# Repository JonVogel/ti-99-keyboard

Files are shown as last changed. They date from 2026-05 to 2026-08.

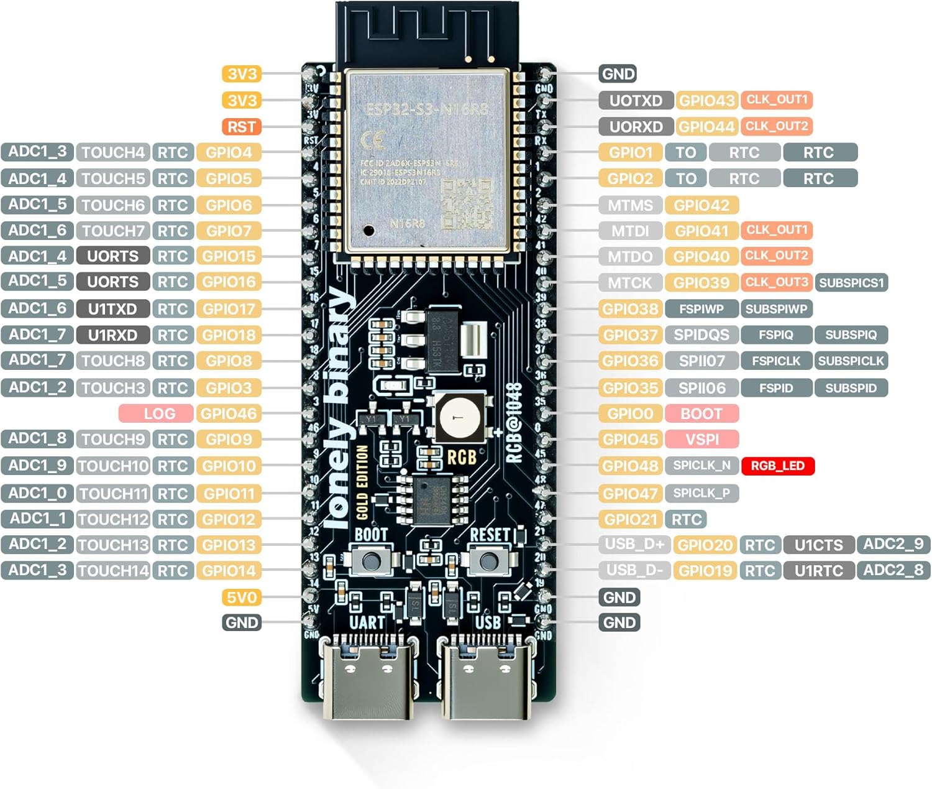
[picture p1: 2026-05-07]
81z4NkTU8bL._AC_SL1500_.jpg

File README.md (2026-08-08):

# TI-99/4A Modern Keyboard Adapter

An ESP32-S3 based adapter that lets you use a modern Bluetooth (or USB) keyboard
with a Texas Instruments TI-99/4A home computer.

The adapter installs inside the TI in place of the original keyboard connector
and emulates the original 6×8 key matrix, translating HID reports from a BLE/USB
keyboard into key presses the console's keyboard scan sees as if they came from
the original keyboard. The original keyboard can optionally run in parallel.

## Features

- **Bluetooth LE keyboard input** using the **NimBLE-Arduino** stack
  - Auto-pairing / "Just Works" bonding on first use
  - Auto-reconnect by saved address after sleep or power cycle
  - **F12** on the keyboard enters pairing mode for a new keyboard
- **Status LED** (onboard WS2812) shows connection state
- Full punctuation and symbol mapping, including the FCTN-generated characters
  (`? _ [ ] { } ' " \ | ~` `` ` `` `: < >`)
- System keys that work on real hardware: **QUIT** (Alt+=) and **CLEAR / BREAK**
  (Alt+4) to stop a running program
- Software **Alpha Lock** that fixes the original joystick-UP bug (see below)
- Optional **parallel original keyboard** — both can drive the matrix at once
- **USB keyboard input** via the native USB-OTG host port (using `EspUsbHost`),
  usable alongside or instead of BLE

## Hardware — Bill of Materials

The adapter comes in **two editions** that are electrically identical and run
the same firmware; they differ only in how the 16 level-shifter channels are
built:

- **DIY edition** (board rev ≤6): all through-hole, level shifting on four
  plug-in BOB-12009 modules — buildable with just a soldering iron.
- **Assembled edition** (board rev 7+): the shifters are 48 SMT parts
  populated by JLCPCB during fabrication. Hand work remaining: the ESP32
  (header pins on the module + two 1×22 sockets on the board, ~88 joints)
  and the connectors — real soldering, just none of the shifter fabric.

### Common parts (both editions)

| Part | Purpose |
|---|---|
| Hosyond ESP32-S3 N16R8 dev board (USB-C, WROOM-1, 16MB flash, 8MB PSRAM) — sold in 3-packs on Amazon | MCU with USB host and BLE |
| 2× 1×22 female socket strips, 2.54mm | Sockets the ESP32 dev board (never solder the module directly) |
| 2× 1×15 male pin headers, 2.54mm (snap from 1×40 breakaway strips — e.g. Adam Tech `PH1-40-UA`, DigiKey ~$0.48/strip) | J10 (to the TI) and J20 (optional original keyboard) |
| 1×2 + 1×1 male header pins (from the same breakaway strips) | J9 bench power header, J15 spare-channel pad |
| TI PSU daisy-chain header — Molex KK-396 4-pin, `09-65-2048` (DigiKey **WM18825-ND**; alt `26-60-4040` / **WM4622-ND**) | Passes the TI's power through the board; the TI mainboard's existing female plug mates here (J14) |
| PSU-side mating plug — Molex `09-50-3041` housing (DigiKey **WM2102-ND**) + 4× `08-50-0106` crimp terminals (DigiKey **WM2300-ND**) + ~30cm of 22 AWG stranded wire | Cable from the J13 solder pads to the TI power supply's header |
| 15-pin female-to-female keyboard ribbon (DIY from bulk Dupont parts, ~$1.5–3.5/cable, no crimping — see note below; or ready-made aftermarket TI ribbon, ~$8) | Connects the adapter's male header to the TI's male keyboard header |

No voltage regulator is needed — the board runs on regulated +5V taken
straight from the TI PSU via the power daisy-chain. Crimp tool for the KK
terminals: IWISS SN-48B (~$20), or fold-and-solder the terminal barrels.

### DIY edition — additional parts (board rev ≤6)

| Part | Purpose |
|---|---|
| PCB fabbed from `pcb/gerbers/ti99-kb-adapter_r6.zip` (2-layer, 1.6mm, HASL — ~$1/board at JLCPCB) | The carrier board, all through-hole |
| 4× BOB-12009 BSS138 level-shifter breakouts (SparkFun ~$3.50 ea, or AliExpress clones) | The 16 shifter channels (4 per module) |
| 8× 1×6 female socket strips, 2.54mm + male header pins on each BOB | Sockets the four BOB modules |

**Solder generously on the BOB headers** — under-heated joints there were the
single most common build fault. Test every finished board with
`test-matrix-loopback/` (onboard LED: green = good, red = bad).

### Assembled edition — what to order (board rev 7+)

| Item | Details |
|---|---|
| JLCPCB order with **PCB Assembly (Economic, Top side)** using the three files in `pcb/gerbers/`: `ti99-kb-adapter_r7.zip` + `ti99-kb-adapter_BOM.csv` + `ti99-kb-adapter_CPL.csv` | Boards arrive with all 48 shifter parts (16× BSS138 `C78284`, 32× 10kΩ `C17414`) machine-soldered — ~$3/board + shipping in qty 10 |

Then add the common parts above. Still hand-soldered: the ESP32 module's
header pins, the two 1×22 board sockets, and all connectors (~120 joints) —
what assembly removes is the shifter fabric and the DIY tier's BOB/socket
work. Run `test-matrix-loopback/` after the ESP32 goes in — LED green means the
whole path (module, sockets, traces, every shifter channel) is proven in
one shot.

The adapter is intended for permanent installation inside a TI-99/4A with the
original keyboard removed (or run in parallel) and a 3D-printed cover over the
keyboard opening.

> **Sourcing the keyboard ribbon (cheap DIY):** the cable is a straight 15-way
> female-to-female run — both the adapter and the TI motherboard expose 1×15 male
> headers. Instead of a ready-made aftermarket TI ribbon (arcadeshopper, ~$8),
> build it from bulk commodity Dupont parts for ~$1.5–3.5/cable with **no
> crimping and no shells to strip**:
> - **15× female-to-female _no-shell_ pre-crimped 2.54mm leads** per cable —
>   [AliExpress](https://www.aliexpress.us/item/3256804990855815.html)
>   (search: *"Dupont 2.54mm female-to-female no-shell pre-crimped jumper wire 40P"*).
> - **2× 1×15 single-row Dupont female housings** per cable —
>   [AliExpress](https://www.aliexpress.us/item/3256806021686798.html)
>   (search: *"Dupont 2.54mm 1x15P housing female single row"*).
>
> Slide 15 bare pins into each housing — that's the whole assembly. A genuine
> Molex 1×15 housing (`50-57-9315`, DigiKey ~$1) also fits, but only accepts Molex
> crimp terminals — commodity Dupont pins won't lock in it, so stay all-Dupont.
> AliExpress links rot; the search terms are the durable fallback. Orientation
> gotcha is noted under the pinout below (red stripe = pin 15).

> **Note:** an earlier revision used TXS0108E auto-direction level shifters. They
> do **not** work for a keyboard matrix — the auto-direction detector can't
> handle open-drain / resistive loads and channels latch or oscillate. The design
> uses **BSS138 discrete MOSFET shifters**, which are bidirectional by physics and
> handle open-drain cleanly. Do not substitute TXS0108E.

## TI-99/4A Keyboard Connector Pinout

The TI's internal keyboard connector is a 1×15 single-row 0.1" header. The console
drives **six column lines** low one at a time (via a 74LS156, pulled up with 1kΩ)
and reads **eight row lines** back (into the TMS9901, pulled up with 10kΩ). The
adapter reads the columns (inputs) and drives the rows (open-drain outputs).

GPIOs below are the **v5 (straight-ribbon) mapping**: the flat ribbon lands
adapter connector (J10) pin *p* on TI pin 16−*p*, and the firmware pin map
mirrors to match. (Rev-3 boards used a 180°-twisted ribbon and a different
GPIO map — see the `v3` git tag.)

| TI pin | Signal | Matrix | ESP32 GPIO | Direction |
|:---:|---|---|:---:|---|
| 1  | INT5  | row 2 | 13 | ESP32 → TI (drive) |
| 2  | INT6  | row 3 | 12 | ESP32 → TI (drive) |
| 3  | INT8  | row 5 | 11 | ESP32 → TI (drive) |
| 4  | INT4  | row 1 | 10 | ESP32 → TI (drive) |
| 5  | INT3  | row 0 | 9  | ESP32 → TI (drive) |
| 6  | P5 | Alpha Lock | 3 | wired, never driven (software alpha lock) |
| 7  | INT7  | row 7 | 8  | ESP32 → TI (drive) |
| 8  | 1Y1 | col 0 | 18 | TI → ESP32 (read) |
| 9  | 1Y0 | col 4 | 17 | TI → ESP32 (read) |
| 10 | INT9  | row 6 | 16 | ESP32 → TI (drive) |
| 11 | INT10 | row 4 | 15 | ESP32 → TI (drive) |
| 12 | 2Y0 | col 5 | 7  | TI → ESP32 (read) |
| 13 | 2Y1 | col 1 | 6  | TI → ESP32 (read) |
| 14 | 2Y2 | col 2 | 5  | TI → ESP32 (read) |
| 15 | 2Y3 | col 3 | 4  | TI → ESP32 (read) |

A 16th level-shifter channel (GPIO14 → **J15 "SPARE" solder pad**) is wired as a
repair path: if any matrix GPIO or shifter channel dies, jumper J15 to the dead
line's pad and remap that line's `#define` to GPIO14 — no board respin needed.

> **Ribbon orientation gotcha:** aftermarket TI keyboard ribbons mark **pin 15**
> with the red stripe, not pin 1. Verify against the silkscreen before plugging in.

### How the matrix output works

A hardware timer samples all six column inputs at ~200 kHz. Each column is
debounced asymmetrically — it becomes *active* on the first LOW sample (so the row
is driven before the ROM reads it) and only releases after two consecutive HIGH
samples (so ribbon coupling can't glitch a held key). The rows driven are the OR
of the pressed keys in every currently-active column, so an ordinary one-column
scan drives exactly that column, while the console's deliberately-overlapping QUIT
and CLEAR scans (which strobe two columns at once) are presented correctly. Rows
are open-drain, so the original keyboard can coexist on the same lines.

The dedicated Alpha Lock line (TI pin 6) is intentionally **never driven** — see
below.

## Software Build

The BLE library `BleHidHost/` lives in-tree and is picked up automatically; the
only external dependency to install is **NimBLE-Arduino**.

### Toolchain

Builds with `arduino-cli` via the included `build.bat` (Windows). FQBN:

```
esp32:esp32:esp32s3:PartitionScheme=no_ota,FlashSize=16M,PSRAM=opi
```

- `build.bat compile` — compile only
- `build.bat` — compile + upload (default COM port)
- `build.bat upload COM7` — upload to a specific port
- `build.bat monitor COM7` — serial monitor at 115200 baud

### Arduino IDE alternative

1. Install **ESP32 board support** (Boards Manager → "esp32 by Espressif")
2. Install **NimBLE-Arduino** (Library Manager → search "NimBLE-Arduino")
3. Point the sketchbook libraries at the in-tree `BleHidHost/` folder (or copy it
   into `~/Documents/Arduino/libraries/`)

### Board settings

- Board: **ESP32S3 Dev Module**
- Flash Size: **16MB**, PSRAM: **OPI PSRAM**, Partition Scheme: **no_ota**
- USB CDC On Boot: **Disabled** (frees the USB-OTG port for host mode; use the
  UART port for the serial monitor)

### Selecting input mode

At the top of `ti-99-keyboard.ino`:

```cpp
// #define INPUT_USB   // USB keyboard via USB-OTG port (currently disabled)
#define INPUT_BLE      // Bluetooth LE HID keyboard
```

## Usage

### First-time BLE pairing

1. Power on the ESP32 — the LED pulses purple (scanning)
2. Put your keyboard in pairing mode
3. The ESP32 finds the keyboard, pairs, bonds, and saves its address to NVS
4. LED turns dim green when ready; it reconnects automatically on later boots

### Re-pairing a different keyboard

Press **F12** on the currently connected keyboard. It disconnects, the ESP32
opens a 30-second pairing window (LED pulses blue), and any HID keyboard put in
pairing mode during that window is adopted as the new peer.

### LED status

| Color | Meaning |
|---|---|
| Pulsing blue | Startup or pairing mode |
| Pulsing purple | Scanning for keyboard |
| Steady dim green | Keyboard connected, idle |
| Bright green flash | Key pressed |
| Red blink | Error |

## Key Mapping

Modifiers pass straight through; the host **Alt** key acts as TI **FCTN**.

| Modern key | TI-99/4A |
|---|---|
| Alt | FCTN |
| Ctrl | CTRL |
| Shift | SHIFT |
| Caps Lock | Alpha Lock (software-emulated; see below) |

Punctuation and symbols (unshifted / shifted):

| Key | Unshifted | Shifted |
|-----|---|---|
| `-` | `-` | `_` (FCTN+U) |
| `=` | `=` | `+` |
| `/` | `/` | `?` (FCTN+I) |
| `;` | `;` | `:` |
| `,` | `,` | `<` |
| `.` | `.` | `>` |
| `'` | `'` (FCTN+O) | `"` (FCTN+P) |
| `[` | `[` (FCTN+R) | `{` (FCTN+F) |
| `]` | `]` (FCTN+T) | `}` (FCTN+G) |
| `\` | `\` (FCTN+Z) | `\|` (FCTN+A) |
| `` ` `` | `` ` `` (FCTN+C) | `~` (FCTN+W) |

Editing / function keys:

| Modern key | TI-99/4A |
|---|---|
| Esc | FCTN+9 (BACK) |
| Backspace | FCTN+S |
| Tab | FCTN+7 |
| Delete | FCTN+1 |
| Arrows | FCTN+E / S / D / X (up / left / right / down) |
| F1–F10 | FCTN+1…0 (DEL, INS, ERASE, CLEAR, BEGIN, PROC'D, AID, REDO, BACK, …) |
| F11 | Toggle type-ahead buffer on/off |
| F12 | Enter BLE pairing mode (not forwarded to the TI) |

The F-key shortcuts let you press the standard TI FCTN+digit combos with a single
key. Two system combos worth calling out, both verified on real hardware:

- **Alt+=** → FCTN+= = **QUIT** (soft-resets to the master title screen)
- **Alt+4** (or **F4**) → FCTN+4 = **CLEAR** (breaks a running BASIC program)

### Alpha Lock and joystick compatibility

The original TI-99/4A has a notorious hardware bug: the Alpha Lock key shares an
electrical signal with joystick UP, so any game played with Alpha Lock engaged
sees a permanent UP input. The classic fix was to physically pop the Alpha Lock
key out of its socket before playing.

This adapter sidesteps the bug entirely by implementing Alpha Lock in software.
When Caps Lock is on, the adapter injects SHIFT into letter keypresses (producing
capital letters via the normal keyboard-scan path) and **never drives the
dedicated Alpha Lock line** (TI pin 6). Joysticks therefore work correctly
regardless of Caps Lock state, and numbers/punctuation are unaffected by Caps
Lock — matching the original Alpha Lock semantics.

## Status

- **BLE keyboard input:** working; tested with the RoyalAxe / ProtoArc L75.
- **TI-99/4A matrix output:** working on real hardware — typing, SHIFT/CTRL/FCTN,
  full punctuation, QUIT, and CLEAR/BREAK, with the original keyboard usable in
  parallel.
- **USB keyboard input:** working — plug a USB keyboard into the ESP32's native
  USB-OTG port (`EspUsbHost`); runs alongside BLE.

## License

MIT — see [LICENSE](LICENSE).

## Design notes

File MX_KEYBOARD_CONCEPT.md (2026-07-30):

# Future project: "B-P board" — MX mechanical keyboard with built-in BLE/USB adapter

Working name: **B-P** (BLE + Physical).
Status: **concept — parked until V5 is bench-validated.** Captured 2026-07-22.
Reference hardware: an **838-MX99 is on order** (~$30 base pre-order) to serve
as the mechanical reference — switch layout in the TI opening, bracket design,
ALPS keycap adapters — and to bench-validate J20 coexistence with the adapter.

## The idea

One keyboard-sized PCB that is both an in-case MX mechanical keyboard for the
TI-99/4A *and* the existing USB/BLE adapter: local MX switches, an ESP32-S3,
and the proven 16-channel BSS138 fabric driving the TI's 6×8 matrix. The TI
only ever sees the synthesized matrix; local keys, BLE keyboards, and USB
keyboards are all just input sources.

## Market context

- **shift838 838-MX99** (2026): drop-in MX replacement keyboard, ~$217
  assembled. Its micro does matrix synthesis (evidenced by alpha-lock memory
  and a destructive backspace — impossible with passive switch wiring), i.e.
  the same architecture class as this project's adapter, fed from local
  switches instead of HID. No BLE/USB.
- **Our differentiator:** the in-case mechanical keyboard is *also* the
  wireless adapter — couch typing over BLE, USB host, plus all existing
  firmware features (software alpha lock/joystick fix, FCTN combos,
  QUIT/CLEAR, type-ahead), field-updatable, on a battle-tested codebase.
- The two products can coexist today: an MX99 (or original keyboard) plugs
  into the adapter's J20. The fusion board makes that one PCB.

## Decisions already made

- **No backlight.** Deliberately scrapped — removes the LED chain, the
  brightness UI, and the TI-PSU current-budget problem entirely.
- **Power: regulated +5V straight from the TI PSU** via the J13/J14
  daisy-chain, same as the adapter (the originally planned 12V→5V buck
  proved unnecessary and is not part of any build).
- **TI-facing half is V5 verbatim** — same 16-channel topology (15 lines +
  SPARE), same firmware pin philosophy, but with the BSS138s + resistors as
  on-board parts (~$3) instead of BOB daughterboards.
- **Local keys are a third input source.** A timer-driven scan (structurally
  the same as the existing debounced column sampler) emits key events into
  the same pipeline `processHidReport` feeds. No new synthesis logic.

## Electrical design points

- **Switch matrix:** ~50 keys (TI's 48 + extras à la MX99's added keys),
  7×8 matrix, **one diode per switch** (NKRO).
- **GPIO budget:** S3 has ~28 comfortable GPIOs; the TI fabric uses 16,
  leaving ~12 — three short of a direct 7×8 scan. Answer: hang the switch
  matrix off **chained 74HC165/595 shift registers** (3–4 GPIOs, any matrix
  size) or an **MCP23017 I²C expander** (2 GPIOs, 16 lines). ~$1–2. The
  fabric keeps its pins, including SPARE.
- **USB-OTG (GPIO19/20) stays reserved** so USB host input remains available.

## The long poles (mechanical, not electrical)

- Switch layout matching the TI keyboard opening; plate; stabilizers
  (6U spacebar per MX99 precedent frees room for extra keys).
- Mounting bracket into the TI case (MX99 ships 3D-printed brackets —
  proves feasibility).
- **Keycaps are the hard/expensive part.** No off-shelf TI legends. Paths:
  generic MX caps (budget), or MX-to-ALPS adapters carrying original TI
  keycaps (838's approach — best authentic look).

## Cost sketch

Switches $15–25 · hot-swap sockets ~$5 · keyboard-size 2-layer PCB ~$5 (JLC)
· ESP32-S3 module ~$6 · on-board shifters ~$3 · connectors/stabs ~$10 ·
caps $20–40 → **BOM ≈ $60–90**, against a $217 assembled competitor with
fewer features.

## Path

1. Fab + bench-validate **V5** (proves fabric, firmware, straight ribbon).
2. Keyboard PCB = V5's TI half + switch matrix + scan chain on one board;
   firmware delta = local scan source.
3. Mechanical design (layout/plate/bracket/caps) in parallel — the real
   schedule driver.
4. End state: two SKUs (adapter, keyboard) sharing one firmware and one
   proven channel design.

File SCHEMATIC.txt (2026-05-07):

TI-99/4A Keyboard Adapter — Wiring Schematic
=============================================

  ESP32-S3 N16R8 dev board (Lonely Binary Gold Edition).
  Physical pin numbers count from pin 1 (3V3) at top of left header
  down to pin 22 (GND) at the bottom. Silkscreen labels in brackets.

                     TI-99/4A +12V Rail
                            |
                   +--------+--------+
                   |  Buck Converter  |
                   |    12V -> 5V     |
                   +--------+--------+
                            |
                          5V Bus ------+----------+----------+
                            |          |          |          |
                            |       TXS#1 VB  TXS#2 VB  ESP32 pin 21 [5V0]
                            |
                          GND Bus -----+----------+----------+----------+
                                       |          |          |          |
                                    TXS#1 GND  TXS#2 GND  ESP32       TI GND
                                                           pin 22 [GND]

                     ESP32 pin 1 [3V3] +----------+----------+----------+
                                       |          |          |          |
                                    TXS#1 VA  TXS#1 OE  TXS#2 VA  TXS#2 OE

  ESP32-S3 N16R8                   TXS0108E #1                      TI Keyboard
  Left Side Header                 (6 rows + 2 cols)                 Connector
  ==================               =================                 =========

  Physical                         A side          B side
  Pin #  [silkscreen]              ------          ------

    1    [3V3] ── (power, see above)
    2    [3V3] ── (power, see above)
    3    [RST] ── (do NOT connect to OE)

    4    [4]  GPIO 4  ─────── A8      B8 ─────────────────── Pin 1  (INT5,  row)
    5    [5]  GPIO 5  ─────── A7      B7 ─────────────────── Pin 2  (INT6,  row)
    6    [6]  GPIO 6  ─────── A6      B6 ─────────────────── Pin 3  (INT8,  row)
    7    [7]  GPIO 7  ─────── A5      B5 ─────────────────── Pin 4  (INT4,  row)
    8    [15] GPIO 15 ─────── A4      B4 ─────────────────── Pin 5  (INT3,  row)
                                                   (nc) ──── Pin 6  (P5, Alpha Lock)
    9    [16] GPIO 16 ─────── A3      B3 ─────────────────── Pin 7  (INT7,  row)
   10    [17] GPIO 17 ─────── A2      B2 ─────────────────── Pin 8  (1Y1,   col 0)
   11    [18] GPIO 18 ─────── A1      B1 ─────────────────── Pin 9  (1Y0,   col 4)

   12    [8]  GPIO 8  ── (unused)
   13    [3]  GPIO 3  ── (unused)
   14    [46] GPIO 46 ── (LOG pin, unused — gap between TXS boards)

                                   TXS0108E #2
                                   (2 rows + 4 cols)

                                   A side          B side
                                   ------          ------

   15    [9]  GPIO 9  ─────── A8      B8 ─────────────────── Pin 10 (INT9,  row)
   16    [10] GPIO 10 ─────── A7      B7 ─────────────────── Pin 11 (INT10, row)
   17    [11] GPIO 11 ─────── A6      B6 ─────────────────── Pin 12 (2Y0,   col 5)
   18    [12] GPIO 12 ─────── A5      B5 ─────────────────── Pin 13 (2Y1,   col 1)
   19    [13] GPIO 13 ─────── A4      B4 ─────────────────── Pin 14 (2Y2,   col 2)
   20    [14] GPIO 14 ─────── A3      B3 ─────────────────── Pin 15 (2Y3,   col 3)
                       (nc) ─ A2      B2 ─────────────────── (nc)
                       (nc) ─ A1      B1 ─────────────────── (nc)

   21    [5V0] ── (power, see above)
   22    [GND] ── (power, see above)

  Signal Flow Summary
  ====================

  Row outputs (ESP32 drives LOW to simulate key press):

      ESP32 ──► TXS A-side ──► TXS B-side ──► TI INT line
      (3.3V)    (level shift)   (5V)           (to TMS9901)

      Pin 4  [4]  GPIO 4  ──►  TI Pin 1   INT5
      Pin 5  [5]  GPIO 5  ──►  TI Pin 2   INT6
      Pin 6  [6]  GPIO 6  ──►  TI Pin 3   INT8
      Pin 7  [7]  GPIO 7  ──►  TI Pin 4   INT4
      Pin 8  [15] GPIO 15 ──►  TI Pin 5   INT3
      Pin 9  [16] GPIO 16 ──►  TI Pin 7   INT7
      Pin 15 [9]  GPIO 9  ──►  TI Pin 10  INT9
      Pin 16 [10] GPIO 10 ──►  TI Pin 11  INT10

  Column inputs (TI's 74LS156 drives LOW to select column):

      TI 74LS156 ──► TXS B-side ──► TXS A-side ──► ESP32
      (5V)           (level shift)   (3.3V)         (digitalRead)

      TI Pin 8   1Y1  ──►  GPIO 17  [17]  Pin 10  (col 0)
      TI Pin 9   1Y0  ──►  GPIO 18  [18]  Pin 11  (col 4)
      TI Pin 12  2Y0  ──►  GPIO 11  [11]  Pin 17  (col 5)
      TI Pin 13  2Y1  ──►  GPIO 12  [12]  Pin 18  (col 1)
      TI Pin 14  2Y2  ──►  GPIO 13  [13]  Pin 19  (col 2)
      TI Pin 15  2Y3  ──►  GPIO 14  [14]  Pin 20  (col 3)

  Notes
  =====

  - TI Pin 6 (P5 / Alpha Lock) is NOT connected. Alpha Lock is
    implemented in software to avoid the TI's joystick-UP bug.

  - TXS#2 channels A2/B2 and A1/B1 are not connected on either side.

  - GPIO 8 (pin 12), GPIO 3 (pin 13), and GPIO 46 (pin 14) sit in the
    physical gap between the two TXS boards and are all unused.

  - Each TXS0108E OE pin must be jumpered to ESP32 pin 1 [3V3]
    to enable the buffer. Do NOT connect OE to pin 3 [RST].

  - The TXS0108E auto-detects signal direction — no DIR pin.

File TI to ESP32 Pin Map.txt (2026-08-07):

v4 connection map (straight ribbon; "TI-n" = J10 connector pin n)

IO4     BOB1-LV4    BOB1-HV4    TI-1  (INT5)
IO5     BOB1-LV3    BOB1-HV3    TI-2  (INT6)
IO6     BOB1-LV2    BOB1-HV2    TI-3  (INT8)
IO7     BOB1-LV1    BOB1-HV1    TI-4  (INT4)
IO15    BOB2-LV4    BOB2-HV4    TI-5  (INT3)
IO16    BOB2-LV3    BOB2-HV3    TI-6  (INT9)
IO17    BOB2-LV2    BOB2-HV2    TI-7  (INT7)
IO18    BOB2-LV1    BOB2-HV1    TI-8  (1Y1)
IO8     BOB3-LV4    BOB3-HV4    TI-9  (1Y0)
IO3     BOB3-LV3    BOB3-HV3    TI-10 (Alpha Lock)
IO9     BOB3-LV2    BOB3-HV2    TI-11 (INT10)
IO10    BOB3-LV1    BOB3-HV1    TI-12 (2Y0)
IO11    BOB4-LV4    BOB4-HV4    TI-13 (2Y1)
IO12    BOB4-LV3    BOB4-HV3    TI-14 (2Y2)
IO13    BOB4-LV2    BOB4-HV2    TI-15 (2Y3)
IO14    BOB4-LV1    BOB4-HV1    SPARE pad (J15)

Notes:
- IO3 (strapping pin) sits on alpha lock, which is never driven -- benign.
- SPARE (IO14 -> J15 pad): jumper to any dead line's pad + remap firmware.
- Through the flat ribbon, J10 pin p lands on TI motherboard pin 16-p.

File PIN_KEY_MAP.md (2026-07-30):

# TI-99/4A Adapter — Pin ↔ Key Debug Map (v5 / straight ribbon)

> **v5 GPIO map** (straight-through ribbon; J10 pin *p* → TI pin 16−*p*).
> For rev-3 boards (180°-twisted ribbon) see this file at the `v3` git tag.

Every key sits at one **column** (read line) and one **row** (drive line), and
works only if BOTH pins are good. So when a *set* of keys dies together, find
the line they share:

- Keys sharing a **column** → that column's read pin is bad.
- Keys sharing a **row** → that row's drive pin is bad.
- A single dead key → its column *or* row (test a neighbor to tell which).

## Column read lines (ESP32 inputs)

| GPIO | TI pin | J10 pin | Col | Keys on this line |
|:----:|:---:|:---:|:---:|---|
| 18 | 8  | 8 | col0 | `/  ;  P  0  Z  A  Q  1` |
| 6  | 13 | 3 | col1 | `.  L  O  9  X  S  W  2` |
| 5  | 14 | 2 | col2 | `,  K  I  8  C  D  E  3` |
| 4  | 15 | 1 | col3 | `M  J  U  7  V  F  R  4` |
| 17 | 9  | 7 | col4 | `N  H  Y  6  B  G  T  5` |
| 7  | 12 | 4 | col5 | `=  Space  Enter  SHIFT  CTRL  FCTN` |

## Row drive lines (ESP32 open-drain outputs)

| GPIO | TI pin | J10 pin | Row | Keys on this line |
|:----:|:---:|:---:|:---:|---|
| 9  | 5  | 11 | row0 | `/  .  ,  M  N  =` |
| 10 | 4  | 12 | row1 | `;  L  K  J  H  Space` |
| 13 | 1  | 15 | row2 | `P  O  I  U  Y  Enter` |
| 12 | 2  | 14 | row3 | `6  7  8  9  0` |
| 15 | 11 | 5  | row4 | `Z  X  C  V  B` |
| 11 | 3  | 13 | row5 | `A  S  D  F  G  SHIFT` |
| 16 | 10 | 6  | row6 | `Q  W  E  R  T  CTRL` |
| 8  | 7  | 9  | row7 | `1  2  3  4  5  FCTN` |

**GPIO3** = Alpha Lock (TI pin 6, J10 pin 10) — wired in v5 but never driven
(software alpha lock); no keys map to it.
**GPIO14** = SPARE repair channel (BOB#4-CH1 → J15 solder pad) — jumper J15 to
any dead line's pad and remap that line's `#define` to 14.

## Notes

- Letters and digits live entirely on **col0–col4**. **col5 (GPIO7 / TI pin 12)**
  carries no letters/digits — only `=`, Space, Enter, and the SHIFT/CTRL/FCTN
  modifiers. A dead col5 → no Enter/Space/modifiers, but normal lowercase typing.
- **BOB grouping** (which daughterboard a line routes through), for knowing
  which channel to reheat — group by **J10 pin**: BOB#1 = J10 1–4,
  BOB#2 = J10 5–8, BOB#3 = J10 9–12, BOB#4 = J10 13–15.
- Quick full-column sweep on one row: **Z X C V B** (row4) or **6 7 8 9 0**
  (row3) hits col0–col4; add **Enter** for col5.

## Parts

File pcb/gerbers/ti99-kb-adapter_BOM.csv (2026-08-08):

Comment | Designator | Footprint | LCSC
10k | R1,R2,R3,R4,R5,R6,R7,R8,R9,R10,R11,R12,R13,R14,R15,R16,R17,R18,R19,R20,R21,R22,R23,R24,R25,R26,R27,R28,R29,R30,R31,R32 | R_0805_2012Metric | C17414
BSS138 | Q1,Q2,Q3,Q4,Q5,Q6,Q7,Q8,Q9,Q10,Q11,Q12,Q13,Q14,Q15,Q16 | SOT-23 | C78284

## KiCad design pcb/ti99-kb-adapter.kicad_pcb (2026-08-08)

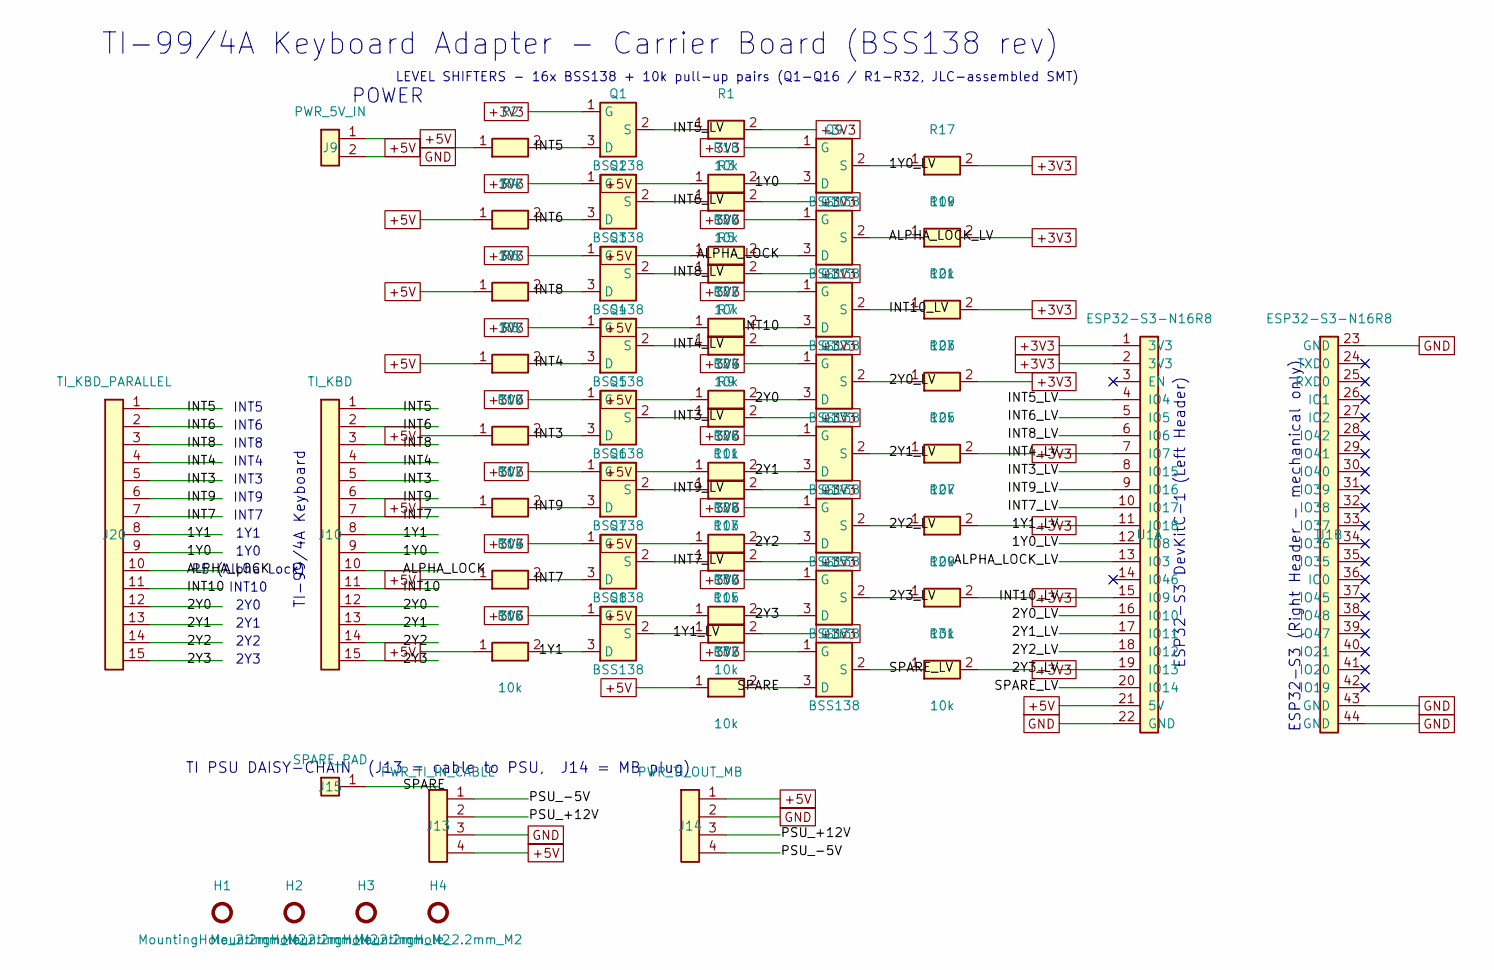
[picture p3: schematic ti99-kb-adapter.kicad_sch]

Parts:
H1, H2, H3, H4: MountingHole_2.2mm_M2
J9: PWR_5V_IN; PinHeader_1x02_P2.54mm_Vertical
J10: TI_KBD; PinHeader_1x15_P2.54mm_Vertical
J13: PWR_TI_IN_CABLE; J13-CableHeader-1x04
J14: PWR_TI_OUT_MB; Molex_KK-396_5273-04A_1x04_P3.96mm_Vertical
J15: SPARE_PAD; PinHeader_1x01_P2.54mm_Vertical
J20: TI_KBD_PARALLEL; PinHeader_1x15_P2.54mm_Vertical
Q1, Q2, Q3, Q4, Q5, Q6, Q7, Q8, Q9, Q10, Q11, Q12, Q13, Q14, Q15, Q16: BSS138; SOT-23; LCSC C78284
R1, R2, R3, R4, R5, R6, R7, R8, R9, R10, R11, R12, R13, R14, R15, R16, R17, R18, R19, R20, R21, R22, R23, R24, R25, R26, R27, R28, R29, R30, R31, R32: 10k; R_0805_2012Metric; LCSC C17414
U1: ESP32-S3-N16R8

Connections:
+3V3: Q1.1 (G), Q2.1 (G), Q3.1 (G), Q4.1 (G), Q5.1 (G), Q6.1 (G), Q7.1 (G), Q8.1 (G), Q9.1 (G), Q10.1 (G), Q11.1 (G), Q12.1 (G), Q13.1 (G), Q14.1 (G), Q15.1 (G), Q16.1 (G), R1.2, R3.2, R5.2, R7.2, R9.2, R11.2, R13.2, R15.2, R17.2, R19.2, R21.2, R23.2, R25.2, R27.2, R29.2, R31.2, U1.1 (3V3), U1.2 (3V3)
+5V: J9.1, J13.4, J14.1, R2.1, R4.1, R6.1, R8.1, R10.1, R12.1, R14.1, R16.1, R18.1, R20.1, R22.1, R24.1, R26.1, R28.1, R30.1, R32.1, U1.21 (5V)
/1Y0: J10.9, J20.9, Q9.3 (D), R18.2
/1Y0_LV: Q9.2 (S), R17.1, U1.12 (IO8)
/1Y1: J10.8, J20.8, Q8.3 (D), R16.2
/1Y1_LV: Q8.2 (S), R15.1, U1.11 (IO18)
/2Y0: J10.12, J20.12, Q12.3 (D), R24.2
/2Y0_LV: Q12.2 (S), R23.1, U1.16 (IO10)
/2Y1: J10.13, J20.13, Q13.3 (D), R26.2
/2Y1_LV: Q13.2 (S), R25.1, U1.17 (IO11)
/2Y2: J10.14, J20.14, Q14.3 (D), R28.2
/2Y2_LV: Q14.2 (S), R27.1, U1.18 (IO12)
/2Y3: J10.15, J20.15, Q15.3 (D), R30.2
/2Y3_LV: Q15.2 (S), R29.1, U1.19 (IO13)
/ALPHA_LOCK: J10.10, J20.10, Q10.3 (D), R20.2
/ALPHA_LOCK_LV: Q10.2 (S), R19.1, U1.13 (IO3)
/INT3: J10.5, J20.5, Q5.3 (D), R10.2
/INT3_LV: Q5.2 (S), R9.1, U1.8 (IO15)
/INT4: J10.4, J20.4, Q4.3 (D), R8.2
/INT4_LV: Q4.2 (S), R7.1, U1.7 (IO7)
/INT5: J10.1, J20.1, Q1.3 (D), R2.2
/INT5_LV: Q1.2 (S), R1.1, U1.4 (IO4)
/INT6: J10.2, J20.2, Q2.3 (D), R4.2
/INT6_LV: Q2.2 (S), R3.1, U1.5 (IO5)
/INT7: J10.7, J20.7, Q7.3 (D), R14.2
/INT7_LV: Q7.2 (S), R13.1, U1.10 (IO17)
/INT8: J10.3, J20.3, Q3.3 (D), R6.2
/INT8_LV: Q3.2 (S), R5.1, U1.6 (IO6)
/INT9: J10.6, J20.6, Q6.3 (D), R12.2
/INT9_LV: Q6.2 (S), R11.1, U1.9 (IO16)
/INT10: J10.11, J20.11, Q11.3 (D), R22.2
/INT10_LV: Q11.2 (S), R21.1, U1.15 (IO9)
/PSU_+12V: J13.2, J14.3
/PSU_-5V: J13.1, J14.4
/SPARE: J15.1 (Pin_1_1), Q16.3 (D), R32.2
/SPARE_LV: Q16.2 (S), R31.1, U1.20 (IO14)
GND: J9.2, J13.3, J14.2, U1.22 (GND), U1.23 (GND), U1.43 (GND), U1.44 (GND)

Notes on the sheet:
INT5
INT6
INT8
INT4
INT3
INT9
INT7
1Y1
1Y0
P5 (Alpha Lock)
INT10
2Y0
2Y1
2Y2
2Y3
TI-99/4A Keyboard Adapter - Carrier Board (BSS138 rev)
POWER
TI PSU DAISY-CHAIN (J13 = cable to PSU, J14 = MB plug)
LEVEL SHIFTERS - 16x BSS138 + 10k pull-up pairs (Q1-Q16 / R1-R32, JLC-assembled SMT)
ESP32-S3 DevKitC-1 (Left Header)
TI-99/4A Keyboard
ESP32-S3 (Right Header - mechanical only)

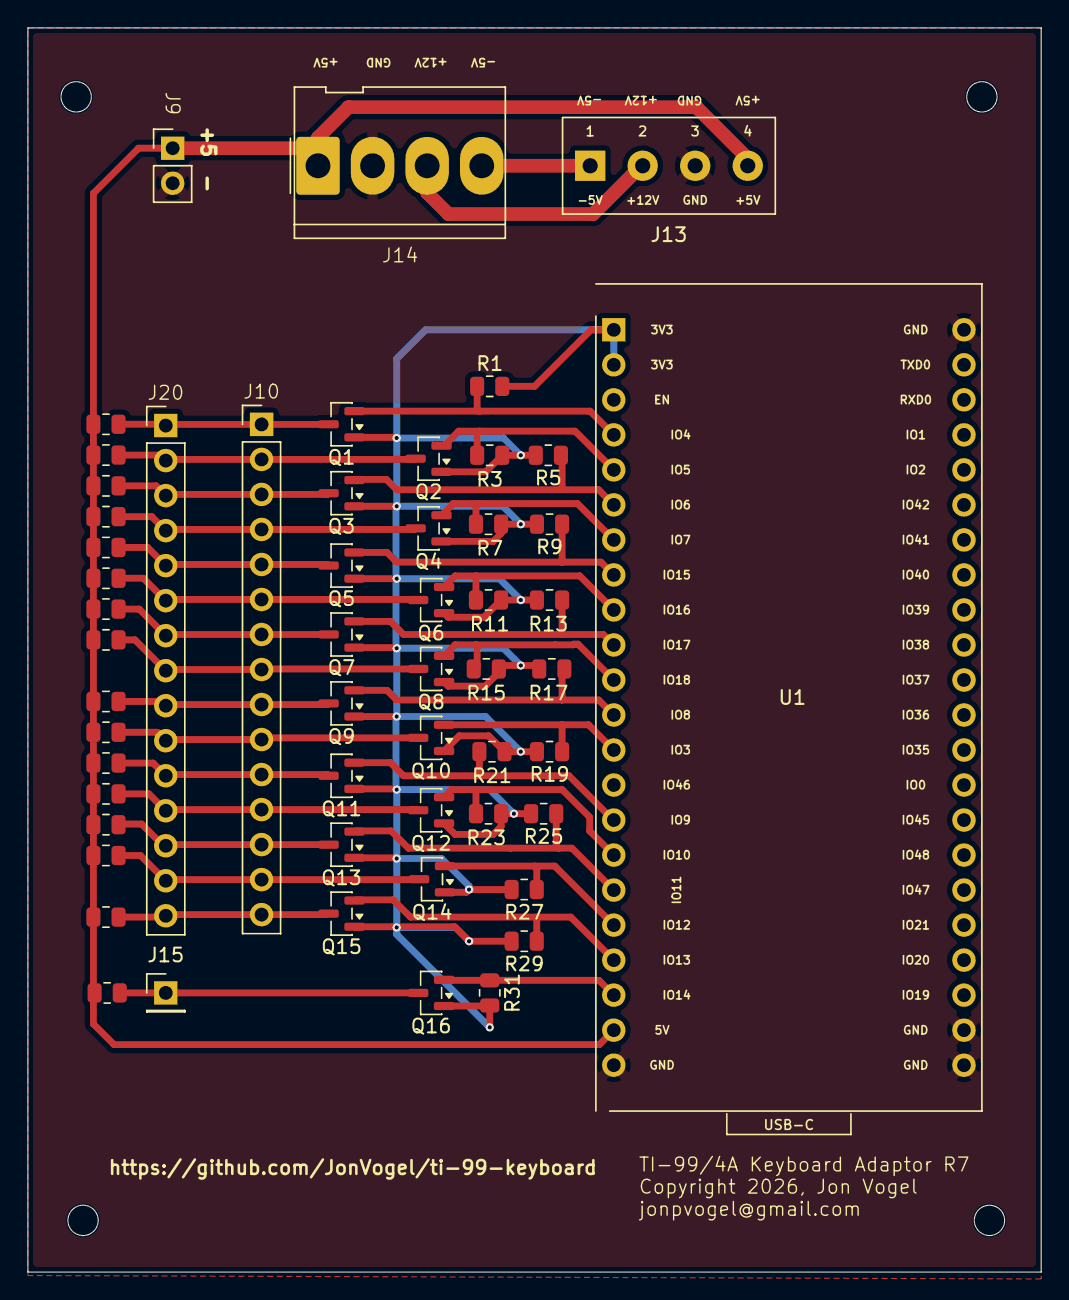
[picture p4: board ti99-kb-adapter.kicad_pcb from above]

Board: 2 copper layers, 73.5 x 90.2 mm, 59 parts (0 on the bottom side), 37 nets.

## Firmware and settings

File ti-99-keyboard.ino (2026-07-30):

/*
 * TI-99/4A USB + Bluetooth Keyboard Adapter
 * For ESP32-S3-DevKitC-1
 *
 * Bridges a USB or Bluetooth keyboard to the TI-99/4A keyboard connector,
 * allowing use of a modern keyboard with the TI home computer.
 *
 * Input modes (select one or both via #define below):
 *   INPUT_USB  - USB keyboard via the USB-OTG port
 *   INPUT_BLE  - Bluetooth Low Energy (BLE) HID keyboard
 *
 * Hardware connections:
 *   ESP32-S3 N16R8 GPIO -> TXS0108E level shifter -> TI-99/4A keyboard connector
 *
 *   Two TXS0108E boards sit along the left edge of the ESP32-S3 N16R8
 *   dev board. TXS#1 uses GPIO 4-18, TXS#2 uses GPIO 9-14. GPIO 46
 *   (LOG pin) sits in the gap between them and is unused.
 *
 *   Each TXS0108E OE pin must be jumpered to ESP32 3V3 to enable.
 *   Do NOT wire OE to RST.
 *
 *   TI keyboard connector wiring (15-pin header):
 *
 *     TI pin  Signal   TXS    Ch    GPIO  Direction
 *     ------  -------  -----  ----  ----  ----------------
 *       1     INT5     TXS#1  B8    4     ESP32 -> TI (row)
 *       2     INT6     TXS#1  B7    5     ESP32 -> TI (row)
 *       3     INT8     TXS#1  B6    6     ESP32 -> TI (row)
 *       4     INT4     TXS#1  B5    7     ESP32 -> TI (row)
 *       5     INT3     TXS#1  B4    15    ESP32 -> TI (row)
 *       6     P5       ---    ---   ---   (nc, software alpha lock)
 *       7     INT7     TXS#1  B3    16    ESP32 -> TI (row)
 *       8     1Y1      TXS#1  B2    17    TI -> ESP32 (col 0)
 *       9     1Y0      TXS#1  B1    18    TI -> ESP32 (col 4)
 *      10     INT9     TXS#2  B8    9     ESP32 -> TI (row)
 *      11     INT10    TXS#2  B7    10    ESP32 -> TI (row)
 *      12     2Y0      TXS#2  B6    11    TI -> ESP32 (col 5)
 *      13     2Y1      TXS#2  B5    12    TI -> ESP32 (col 1)
 *      14     2Y2      TXS#2  B4    13    TI -> ESP32 (col 2)
 *      15     2Y3      TXS#2  B3    14    TI -> ESP32 (col 3)
 *
 * Board settings (Arduino IDE):
 *   Board: "ESP32S3 Dev Module"
 *   USB Mode: "USB-OTG (TinyUSB)" (if using USB input)
 *   USB CDC On Boot: "Disabled" (use UART port for serial monitor)
 *
 * Libraries required:
 *   - EspUsbHost by tanakamasayuki (for USB input)
 *   - BLE uses the built-in ESP32 BLE library (Bluedroid stack)
 */

// ---------------------------------------------------------------------------
// Input Mode Selection — uncomment one or both
// ---------------------------------------------------------------------------
#define INPUT_USB  // USB keyboard via USB-OTG host port (EspUsbHost)
#define INPUT_BLE

// ---------------------------------------------------------------------------
// Type-ahead Buffer
// ---------------------------------------------------------------------------
// The original TI-99/4A has no keyboard buffer — keys typed faster than the
// console's matrix scan get dropped. The IBM PC's BIOS solved this with a
// 16-key type-ahead buffer that captured keystrokes at interrupt time and
// fed them to the console at scan rate. The same trick is implemented here:
// HID key-down events get queued (with their modifiers snapshotted at press
// time), then a replay state machine holds each one on the TI matrix long
// enough for the ROM to definitely see it before serving the next.
//
// The buffer breaks games that depend on "is this key DOWN right now?"
// (Parsec hold-to-fire, TI Invaders movement, etc.) — held keys turn into
// 40ms pulses, multi-key chords get serialized. So the buffer is OFF by
// default and the user toggles it on/off at runtime with F11. Compile-flag
// gates the whole feature in case the runtime path proves problematic on
// real hardware.
#define ENABLE_TYPE_AHEAD_BUFFER

// Tunables. HOLD_MS must cover at least 2 TI keyboard scan cycles so the
// ROM is guaranteed to sample the matrix while the key is asserted.
// GAP_MS gives the ROM a chance to see the release between consecutive
// presses of the same key (otherwise back-to-back AAA looks like one A).
#define TYPE_AHEAD_DEPTH    16
#define TYPE_AHEAD_HOLD_MS  40
#define TYPE_AHEAD_GAP_MS   10

#ifdef INPUT_USB
#include <EspUsbHost.h>
#endif

#ifdef INPUT_BLE
#include <BleHidHost.h>
#endif

// ---------------------------------------------------------------------------
// Status LED (onboard WS2812 RGB LED on GPIO 48)
// ---------------------------------------------------------------------------
#define PIN_LED        48
#define LED_BRIGHTNESS 20

enum LedState
{
  LED_STARTUP,
  LED_SCANNING,
  LED_CONNECTED,
  LED_KEYPRESS,
  LED_ERROR,
  LED_NO_INPUT
};

static LedState currentLedState = LED_STARTUP;
static unsigned long ledStateTime = 0;
static unsigned long keypressTime = 0;

// True while a USB keyboard is enumerated on the host port. EspUsbHost's
// usbTransferSize goes >0 on enumerate and back to 0 on unplug, so we mirror
// it each loop. Drives the status LED orange so it's obvious USB is the live
// input. Stays false when INPUT_USB is compiled out.
static bool usbInUse = false;

void setLed(uint8_t r, uint8_t g, uint8_t b)
{
  rgbLedWrite(PIN_LED, r, g, b);
}

void setLedState(LedState state)
{
  if (state != currentLedState)
  {
    currentLedState = state;
    ledStateTime = millis();
  }
}

void updateLed()
{
  unsigned long now = millis();
  int pulse = (sin(now / 300.0) + 1.0) * LED_BRIGHTNESS / 2;

  if (now - keypressTime < 100)
  {
    setLed(0, LED_BRIGHTNESS * 3, 0);
    return;
  }

  // USB keyboard connected → steady orange, overriding the BLE-driven states
  // below. (Keypress flash above still wins momentarily for feedback.)
  if (usbInUse)
  {
    setLed(LED_BRIGHTNESS, LED_BRIGHTNESS / 4, 0);
    return;
  }

  switch (currentLedState)
  {
    case LED_STARTUP:
      setLed(0, 0, pulse);
      break;
    case LED_SCANNING:
      setLed(pulse, 0, pulse);
      break;
    case LED_CONNECTED:
      setLed(0, LED_BRIGHTNESS / 4, 0);
      break;
    case LED_KEYPRESS:
      setLed(0, LED_BRIGHTNESS * 3, 0);
      break;
    case LED_ERROR:
      if ((now / 250) % 2)
      {
        setLed(LED_BRIGHTNESS, 0, 0);
      }
      else
      {
        setLed(0, 0, 0);
      }
      break;
    case LED_NO_INPUT:
      setLed(LED_BRIGHTNESS / 4, LED_BRIGHTNESS / 6, 0);
      break;
  }
}

// ---------------------------------------------------------------------------
// GPIO Pin Assignments
// ---------------------------------------------------------------------------
// Both TXS0108E boards sit along the left edge of the ESP32-S3 N16R8 dev
// board. TXS#1 uses GPIO 4-18 (8 channels), TXS#2 uses GPIO 9-14
// (6 channels). GPIO 46 (LOG pin) sits in the gap and is unused.
//
// ESP32 -> TXS#1:  GPIO4=A8, 5=A7, 6=A6, 7=A5, 15=A4, 16=A3, 17=A2, 18=A1
// ESP32 -> TXS#2:  GPIO9=A8, 10=A7, 11=A6, 12=A5, 13=A4, 14=A3
//
// TXS#1 B-side -> TI: B8=pin1, B7=pin2, B6=pin3, B5=pin4, B4=pin5,
//                      B3=pin7, B2=pin8, B1=pin9   (pin6=P5 nc)
// TXS#2 B-side -> TI: B8=pin10, B7=pin11, B6=pin12, B5=pin13,
//                      B4=pin14, B3=pin15

// ---------------------------------------------------------------------------
// v5 straight-cable GPIO remap  (rev-3 twisted-ribbon baseline is tagged v3)
// ---------------------------------------------------------------------------
// The 1x15 keyboard ribbon reverses pin order end-to-end because of the
// connector orientation (J10 pin p <-> TI-motherboard pin 16-p), so rev 1-3
// only worked with the ribbon TWISTED 180 degrees. v5 targets a plain
// STRAIGHT (untwisted) ribbon.
//
// The 14 driven/read matrix lines are remapped here in firmware: each signal
// now uses the GPIO whose J10 pin mirrors (16-p) to the correct TI pin. It's
// a pure relabel -- the matrix tables further down are unchanged.
//
// Alpha-lock (TI pin 6, J10 pin 10) is no longer a bare pass-through: the v5
// board gives it a level-shifter channel and GPIO9, so EVERY TI line is now
// reachable from firmware -- future re-pinning never needs a new layout. The
// firmware still never drives it (software alpha lock; driving the line
// breaks joystick UP), but the copper is there.
//
// v5 board channel fabric (GPIO -> BOB channel -> J10 pin), per Jon's map:
//   BOB1: GPIO4-7      -> CH4..CH1 -> J10 1-4
//   BOB2: GPIO15-18    -> CH4..CH1 -> J10 5-8
//   BOB3: GPIO8,3,9,10 -> CH4..CH1 -> J10 9-12  (GPIO3 = alpha, J10 10)
//   BOB4: GPIO11-13    -> CH4..CH2 -> J10 13-15
//         GPIO14       -> CH1      -> SPARE solder pad (J15)
//
// WARNING: do NOT flash this build onto a rev-3 board with a twisted ribbon;
// the double reversal scrambles the matrix.

// Row outputs — ESP32 -> TI  (GPIO -> J10 pin -> straight ribbon -> TI pin)
#define PIN_ROW_INT5  13   // GPIO13 -> J10 p15 -> TI pin 1
#define PIN_ROW_INT6  12   // GPIO12 -> J10 p14 -> TI pin 2
#define PIN_ROW_INT8  11   // GPIO11 -> J10 p13 -> TI pin 3
#define PIN_ROW_INT4  10   // GPIO10 -> J10 p12 -> TI pin 4
#define PIN_ROW_INT3   9   // GPIO9  -> J10 p11 -> TI pin 5
#define PIN_ROW_INT7   8   // GPIO8  -> J10 p9  -> TI pin 7
#define PIN_ROW_INT9  16   // GPIO16 -> J10 p6  -> TI pin 10
#define PIN_ROW_INT10 15   // GPIO15 -> J10 p5  -> TI pin 11

// Column inputs — TI -> ESP32
#define PIN_COL_1Y1   18   // GPIO18 -> J10 p8  -> TI pin 8  (col 0)
#define PIN_COL_1Y0   17   // GPIO17 -> J10 p7  -> TI pin 9  (col 4)
#define PIN_COL_2Y0    7   // GPIO7  -> J10 p4  -> TI pin 12 (col 5)
#define PIN_COL_2Y1    6   // GPIO6  -> J10 p3  -> TI pin 13 (col 1)
#define PIN_COL_2Y2    5   // GPIO5  -> J10 p2  -> TI pin 14 (col 2)
#define PIN_COL_2Y3    4   // GPIO4  -> J10 p1  -> TI pin 15 (col 3)

// Alpha Lock — wired in v5 (GPIO3 -> J10 p10 -> TI pin 6 / P5) but NEVER
// driven: kept INPUT for the life of the sketch. Software alpha lock injects
// SHIFT instead; driving this line breaks joystick UP on unmodified consoles.
// GPIO3 is an S3 strapping pin (JTAG select) -- harmless here precisely
// because the line is never driven and its boot-time pull-up is benign.
#define PIN_ALPHA_LOCK 3

// Spare repair channel — GPIO14 -> BOB#4-CH1 -> J15 solder pad. If any
// matrix GPIO or shifter channel dies, jumper J15 to the dead line's pad
// and point that line's define here. See PIN_KEY_MAP.md.
// #define PIN_SPARE 14

static const int colPins[6] =
{
  PIN_COL_1Y1, PIN_COL_2Y1, PIN_COL_2Y2,
  PIN_COL_2Y3, PIN_COL_1Y0, PIN_COL_2Y0
};

static const int rowPins[8] =
{
  PIN_ROW_INT3, PIN_ROW_INT4, PIN_ROW_INT5, PIN_ROW_INT6,
  PIN_ROW_INT10, PIN_ROW_INT8, PIN_ROW_INT9, PIN_ROW_INT7
};

// ---------------------------------------------------------------------------
// TI-99/4A Keyboard Matrix
// ---------------------------------------------------------------------------
// Column index: 0=1Y1, 1=2Y1, 2=2Y2, 3=2Y3, 4=1Y0, 5=2Y0
// Row index:    0=INT3, 1=INT4, 2=INT5, 3=INT6, 4=INT10, 5=INT8, 6=INT9, 7=INT7
//
// Col 0 (1Y1): =  ;  P  0  Z  A  Q  1
// Col 1 (2Y1): .  L  O  9  X  S  W  2
// Col 2 (2Y2): ,  K  I  8  C  D  E  3
// Col 3 (2Y3): M  J  U  7  V  F  R  4
// Col 4 (1Y0): N  H  Y  6  B  G  T  5
// Col 5 (2Y0): (=) SPC ENT  -  -  SHIFT CTRL FCTN

// ---------------------------------------------------------------------------
// Key State (shared between USB and BLE input)
// ---------------------------------------------------------------------------
static volatile uint8_t keyState[6] = {0, 0, 0, 0, 0, 0};
static volatile bool alphaLockActive = false;

// ---------------------------------------------------------------------------
// HID Scancode Definitions
// ---------------------------------------------------------------------------
#define HID_KEY_A          0x04
#define HID_KEY_B          0x05
#define HID_KEY_C          0x06
#define HID_KEY_D          0x07
#define HID_KEY_E          0x08
#define HID_KEY_F          0x09
#define HID_KEY_G          0x0A
#define HID_KEY_H          0x0B
#define HID_KEY_I          0x0C
#define HID_KEY_J          0x0D
#define HID_KEY_K          0x0E
#define HID_KEY_L          0x0F
#define HID_KEY_M          0x10
#define HID_KEY_N          0x11
#define HID_KEY_O          0x12
#define HID_KEY_P          0x13
#define HID_KEY_Q          0x14
#define HID_KEY_R          0x15
#define HID_KEY_S          0x16
#define HID_KEY_T          0x17
#define HID_KEY_U          0x18
#define HID_KEY_V          0x19
#define HID_KEY_W          0x1A
#define HID_KEY_X          0x1B
#define HID_KEY_Y          0x1C
#define HID_KEY_Z          0x1D
#define HID_KEY_1          0x1E
#define HID_KEY_2          0x1F
#define HID_KEY_3          0x20
#define HID_KEY_4          0x21
#define HID_KEY_5          0x22
#define HID_KEY_6          0x23
#define HID_KEY_7          0x24
#define HID_KEY_8          0x25
#define HID_KEY_9          0x26
#define HID_KEY_0          0x27
#define HID_KEY_ENTER      0x28
#define HID_KEY_ESCAPE     0x29
#define HID_KEY_BACKSPACE  0x2A
#define HID_KEY_TAB        0x2B
#define HID_KEY_SPACE      0x2C
#define HID_KEY_MINUS        0x2D
#define HID_KEY_EQUAL        0x2E
#define HID_KEY_LEFTBRACKET  0x2F
#define HID_KEY_RIGHTBRACKET 0x30
#define HID_KEY_BACKSLASH    0x31
#define HID_KEY_SEMICOLON    0x33
#define HID_KEY_APOSTROPHE   0x34
#define HID_KEY_GRAVE        0x35
#define HID_KEY_COMMA        0x36
#define HID_KEY_PERIOD       0x37
#define HID_KEY_SLASH        0x38
#define HID_KEY_CAPSLOCK     0x39
#define HID_KEY_F1         0x3A
#define HID_KEY_F2         0x3B
#define HID_KEY_F3         0x3C
#define HID_KEY_F4         0x3D
#define HID_KEY_F5         0x3E
#define HID_KEY_F6         0x3F
#define HID_KEY_F7         0x40
#define HID_KEY_F8         0x41
#define HID_KEY_F9         0x42
#define HID_KEY_F10        0x43
#define HID_KEY_F11        0x44
#define HID_KEY_F12        0x45
#define HID_KEY_RIGHT      0x4F
#define HID_KEY_LEFT       0x50
#define HID_KEY_DOWN       0x51
#define HID_KEY_UP         0x52
#define HID_KEY_DELETE     0x4C

#define HID_MOD_LCTRL   0x01
#define HID_MOD_LSHIFT  0x02
#define HID_MOD_LALT    0x04
#define HID_MOD_RCTRL   0x10
#define HID_MOD_RSHIFT  0x20
#define HID_MOD_RALT    0x40

// Row bitmasks
#define ROW0  0x01  // INT3
#define ROW1  0x02  // INT4
#define ROW2  0x04  // INT5
#define ROW3  0x08  // INT6
#define ROW4  0x10  // INT10
#define ROW5  0x20  // INT8
#define ROW6  0x40  // INT9
#define ROW7  0x80  // INT7

// TI modifier key positions (column 5 = 2Y0)
#define TI_SHIFT_COL  5
#define TI_SHIFT_ROW  ROW5
#define TI_CTRL_COL   5
#define TI_CTRL_ROW   ROW6
#define TI_FCTN_COL   5
#define TI_FCTN_ROW   ROW7

// ---------------------------------------------------------------------------
// HID Scancode to TI Matrix Lookup Table
// ---------------------------------------------------------------------------
typedef struct
{
  uint8_t col;
  uint8_t row;
} TiKeyMapping;

#define MAP_SIZE 0x53
static const TiKeyMapping hidToTi[MAP_SIZE] =
{
  {0xFF, 0}, {0xFF, 0}, {0xFF, 0}, {0xFF, 0},       // 0x00-0x03: reserved
  {0, ROW5},  {4, ROW4},  {2, ROW4},  {2, ROW5},    // A B C D
  {2, ROW6},  {3, ROW5},  {4, ROW5},  {4, ROW1},    // E F G H
  {2, ROW2},  {3, ROW1},  {2, ROW1},  {1, ROW1},    // I J K L
  {3, ROW0},  {4, ROW0},  {1, ROW2},  {0, ROW2},    // M N O P
  {0, ROW6},  {3, ROW6},  {1, ROW5},  {4, ROW6},    // Q R S T
  {3, ROW2},  {3, ROW4},  {1, ROW6},  {1, ROW4},    // U V W X
  {4, ROW2},  {0, ROW4},                              // Y Z
  {0, ROW7},  {1, ROW7},  {2, ROW7},  {3, ROW7},    // 1 2 3 4
  {4, ROW7},  {4, ROW3},  {3, ROW3},  {2, ROW3},    // 5 6 7 8
  {1, ROW3},  {0, ROW3},                              // 9 0
  {5, ROW2},                                           // Enter
  {0xFF, 0}, {0xFF, 0}, {0xFF, 0},                    // Esc, BS, Tab (special)
  {5, ROW1},                                           // Space
  {0xFF, 0},                                           // Minus    (punctKeys)
  {0xFF, 0},                                           // Equal    (punctKeys)
  {0xFF, 0}, {0xFF, 0}, {0xFF, 0}, {0xFF, 0},         // [ ] \ (punctKeys), #
  {0, ROW1},                                           // Semicolon
  {0xFF, 0}, {0xFF, 0},                                // ' ` (punctKeys)
  {2, ROW0},                                           // Comma
  {1, ROW0},                                           // Period
  {0xFF, 0},                                           // Slash    (punctKeys)
  {0xFF, 0},                                           // Caps Lock (special)
  {0xFF, 0}, {0xFF, 0}, {0xFF, 0}, {0xFF, 0}, {0xFF, 0},  // F1-F5
  {0xFF, 0}, {0xFF, 0}, {0xFF, 0}, {0xFF, 0}, {0xFF, 0},  // F6-F10
  {0xFF, 0}, {0xFF, 0}, {0xFF, 0}, {0xFF, 0}, {0xFF, 0},  // F11-misc
  {0xFF, 0}, {0xFF, 0}, {0xFF, 0}, {0xFF, 0}, {0xFF, 0}, {0xFF, 0},
  {0xFF, 0}, {0xFF, 0}, {0xFF, 0}, {0xFF, 0},             // arrows (special)
};

// ---------------------------------------------------------------------------
// Special Key Combos (require FCTN or SHIFT + another key)
// ---------------------------------------------------------------------------
typedef struct
{
  uint8_t hidKey;
  uint8_t tiCol;
  uint8_t tiRow;
  bool    needFctn;
  bool    needShift;
} SpecialKeyMapping;

static const SpecialKeyMapping specialKeys[] =
{
  {HID_KEY_UP,        2, ROW6, true, false},  // FCTN+E
  {HID_KEY_DOWN,      1, ROW4, true, false},  // FCTN+X
  {HID_KEY_LEFT,      1, ROW5, true, false},  // FCTN+S
  {HID_KEY_RIGHT,     2, ROW5, true, false},  // FCTN+D
  {HID_KEY_ESCAPE,    1, ROW3, true, false},  // FCTN+9 (BACK)
  {HID_KEY_BACKSPACE, 1, ROW5, true, false},  // FCTN+S (LEFT)
  {HID_KEY_TAB,       3, ROW3, true, false},  // FCTN+7
  {HID_KEY_DELETE,    0, ROW7, true, false},  // FCTN+1 (DEL)
  {HID_KEY_F1,        0, ROW7, true, false},  // FCTN+1
  {HID_KEY_F2,        1, ROW7, true, false},  // FCTN+2
  {HID_KEY_F3,        2, ROW7, true, false},  // FCTN+3
  {HID_KEY_F4,        3, ROW7, true, false},  // FCTN+4
  {HID_KEY_F5,        4, ROW7, true, false},  // FCTN+5
  {HID_KEY_F6,        4, ROW3, true, false},  // FCTN+6
  {HID_KEY_F7,        3, ROW3, true, false},  // FCTN+7
  {HID_KEY_F8,        2, ROW3, true, false},  // FCTN+8
  {HID_KEY_F9,        1, ROW3, true, false},  // FCTN+9
  {HID_KEY_F10,       0, ROW3, true, false},  // FCTN+0
};
#define NUM_SPECIAL_KEYS (sizeof(specialKeys) / sizeof(specialKeys[0]))

// ---------------------------------------------------------------------------
// Shift-dependent punctuation
// ---------------------------------------------------------------------------
// US-keyboard punctuation keys whose TI-99/4A production differs between the
// unshifted and shifted forms — and where the shifted form often needs FCTN
// (not SHIFT) and a completely different matrix cell. The generic "pass the
// physical SHIFT through to a base key" rule can't express this, so these
// keys are resolved here from the live modifier state instead.
//
// Each entry gives the TI matrix cell (col + row bitmask) and which TI
// modifier to add, separately for the unshifted (u*) and shifted (s*) forms.
//
// Matrix positions verified against Thierry Nouspikel's TI-99/4A keyboard
// matrix (unige.ch/.../ti99/keyboard.htm), mapped to this sketch's proven
// col/row numbering via the working letter/number cells. Notably `/` lives
// at {col0,ROW0} and `=` at {col5,ROW0} — NOT the other way around.
//
// Reference — TI produces:
//   -  SHIFT+/      _  FCTN+U        =  (base {5,R0})   +  SHIFT+=
//   /  (base {0,R0}) ?  FCTN+I       ;  (base {0,R1})   :  SHIFT+;
//   ,  (base {2,R0}) <  SHIFT+,      .  (base {1,R0})   >  SHIFT+.
//   '  FCTN+O        "  FCTN+P       `  FCTN+C          ~  FCTN+W
//   [  FCTN+R        {  FCTN+F       ]  FCTN+T          }  FCTN+G
//   \  FCTN+Z        |  FCTN+A
#define M_NONE  0
#define M_SHIFT 1
#define M_FCTN  2

typedef struct
{
  uint8_t hidKey;
  uint8_t uCol, uRow, uMod;   // unshifted form
  uint8_t sCol, sRow, sMod;   // shifted form
} PunctKeyMapping;

static const PunctKeyMapping punctKeys[] =
{
  // HID key               unshifted → TI          shifted → TI
  {HID_KEY_MINUS,        0, ROW0, M_SHIFT,      3, ROW2, M_FCTN },  // -  / _
  {HID_KEY_EQUAL,        5, ROW0, M_NONE,       5, ROW0, M_SHIFT},  // =  / +
  {HID_KEY_SEMICOLON,    0, ROW1, M_NONE,       0, ROW1, M_SHIFT},  // ;  / :
  {HID_KEY_COMMA,        2, ROW0, M_NONE,       2, ROW0, M_SHIFT},  // ,  / <
  {HID_KEY_PERIOD,       1, ROW0, M_NONE,       1, ROW0, M_SHIFT},  // .  / >
  {HID_KEY_SLASH,        0, ROW0, M_NONE,       2, ROW2, M_FCTN },  // /  / ?
  {HID_KEY_APOSTROPHE,   1, ROW2, M_FCTN,       0, ROW2, M_FCTN },  // '  / "
  {HID_KEY_LEFTBRACKET,  3, ROW6, M_FCTN,       3, ROW5, M_FCTN },  // [  / {
  {HID_KEY_RIGHTBRACKET, 4, ROW6, M_FCTN,       4, ROW5, M_FCTN },  // ]  / }
  {HID_KEY_BACKSLASH,    0, ROW4, M_FCTN,       0, ROW5, M_FCTN },  // \  / |
  {HID_KEY_GRAVE,        2, ROW4, M_FCTN,       1, ROW6, M_FCTN },  // `  / ~
};
#define NUM_PUNCT_KEYS (sizeof(punctKeys) / sizeof(punctKeys[0]))
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
void loop()
{
  processSerialDebug();

  // Drain the strobe-observation ring buffer to serial. Active only when
  // 'observe' mode is on; otherwise this is a one-flag-check no-op.
  strobeObserveDrain();

  if (!debugMode)
  {
#ifdef INPUT_USB
    usbHost.task();
    usbInUse = (usbHost.usbTransferSize > 0);
#endif

#ifdef INPUT_BLE
    bleTask();
#endif

#ifdef ENABLE_TYPE_AHEAD_BUFFER
    processTypeAheadBuffer();
#endif

    // Row outputs are driven by the timer-sampled column scanner
    // (onMatrixTimer); nothing to do here.
  }

  updateLed();
}

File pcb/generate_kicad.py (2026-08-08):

#!/usr/bin/env python3
"""
Generate KiCad 10 project files for TI-99/4A Keyboard Adapter carrier board.

This board is a simple carrier that sockets off-the-shelf modules:
  - ESP32-S3 DevKitC-1 LBGE (via 2x 1x22 pin sockets, 25.4mm row spacing)
  - 4x BSS138 4-channel level shifter breakouts (BOB-12009 style),
    each via 2x 1x6 pin sockets at 10mm row spacing
  - 1x15 pin header for TI-99/4A keyboard ribbon
  - 1x2 pin header for 5V power input

The PCB has no active components -- just headers and copper traces.

History: previous rev used 2x TXS0108E modules, but TXS auto-direction
detection fails on open-drain matrix emulation (latch-up, indeterminate
levels, documented pad damage). BSS138 + pull-ups is the correct topology
for a matrix; validated on bench 2026-04-20.

BOB-12009 (SparkFun BSS138) socket pin mapping, confirmed from physical board:
  LV socket pin: 1=LV4, 2=LV3, 3=GND, 4=LV(3V3), 5=LV2, 6=LV1
  HV socket pin: 1=HV4, 2=HV3, 3=GND, 4=HV(5V),  5=HV2, 6=HV1
Channel-to-socket-pin: CH1=pin 6, CH2=pin 5, CH3=pin 2, CH4=pin 1
GNDs at pin 3, rails at pin 4. GND and rails are directly opposite
across the board.

Net naming: the LV and HV sides of each BOB are electrically isolated
through the BSS138 MOSFET, so LV-side pins get a "<sig>_LV" net while
HV-side pins get the bare "<sig>" net. Same-name nets would short LV
to HV in the schematic.

Channel allocation (14 of 16 used). Chosen for contiguous, non-crossing
trace flow: each BOB takes a sequential block of GPIOs AND a sequential
block of TI pins, with BOBs ordered top-to-bottom matching both:
  BOB#1 (top):    GPIO 4-7   <-> TI 1-4
  BOB#2:          GPIO 15-18 <-> TI 5,7,8,9   (TI 6 NC, Alpha Lock)
  BOB#3:          GPIO 9-12  <-> TI 10-13
  BOB#4 (bottom): GPIO 13-14 <-> TI 14-15     (CH3/CH4 unused)

Usage:
  python generate_kicad.py
  Open ti99-kb-adapter.kicad_pro in KiCad 10.
  Press F8 (Update PCB from Schematic) to create the board layout.
  Footprint suggestion: Connector_PinSocket_2.54mm:PinSocket_1x06_P2.54mm_Vertical
  for each BOB side. Place the two sockets per BOB 10mm apart.
"""

import uuid
import json
import os
import sys

# Allow `python generate_kicad.py` from any cwd by ensuring this script's
# directory is on the import path so generate_parts can be imported.
sys.path.insert(0, os.path.dirname(os.path.abspath(__file__)))
from generate_parts import bob_12009_symbol, esp32_symbol  # noqa: E402

PROJECT = "ti99-kb-adapter"


_UID_NS = uuid.uuid5(uuid.NAMESPACE_DNS, "ti99-kb-adapter.jonvogel")
_uid_counter = 0


def uid():
    """Deterministic UUIDs: the Nth call always returns the same value,
    so regenerating an unchanged design produces a byte-identical file
    (no git churn) and KiCad's UUID-based links survive regeneration."""
    global _uid_counter
    _uid_counter += 1
    return str(uuid.uuid5(_UID_NS, str(_uid_counter)))


# ---------------------------------------------------------------------------
# KiCad symbol definition for Connector_Generic:Conn_01xNN
# ---------------------------------------------------------------------------
def conn_sym_def(n):
    """Return embedded symbol definition for a 1xN connector."""
    name = f"Connector_Generic:Conn_01x{n:02d}"
    sub = f"Conn_01x{n:02d}_1_1"
    fy = (n - 1) / 2 * 2.54          # y of pin 1 (top)
    rt = fy + 1.27                     # rectangle top
    rb = -(fy + 1.27)                  # rectangle bottom

    pins = []
    for k in range(1, n + 1):
        py = fy - (k - 1) * 2.54
        pins.append(
            f"        (pin passive line (at 5.08 {py:.2f} 180) (length 3.81)\n"
            f'          (name "Pin_{k}" (effects (font (size 1.27 1.27))))\n'
            f'          (number "{k}" (effects (font (size 1.27 1.27)))))'
        )

    return (
        f'    (symbol "{name}"\n'
        f"      (pin_names (offset 1.016) hide)\n"
        f"      (exclude_from_sim no) (in_bom yes) (on_board yes)\n"
        f'      (property "Reference" "J" (at 0 {rt + 1.27:.2f} 0)\n'
        f"        (effects (font (size 1.27 1.27))))\n"
        f'      (property "Value" "Conn_01x{n:02d}" (at 0 {rb - 1.27:.2f} 0)\n'
        f"        (effects (font (size 1.27 1.27))))\n"
        f'      (property "Footprint" "" (at 0 0 0)\n'
        f"        (effects (font (size 1.27 1.27)) (hide yes)))\n"
        f'      (property "Datasheet" "~" (at 0 0 0)\n'
        f"        (effects (font (size 1.27 1.27)) (hide yes)))\n"
        f'      (symbol "{sub}"\n'
        f"        (rectangle (start -1.27 {rt:.2f}) (end 1.27 {rb:.2f})\n"
        f"          (stroke (width 0.254) (type default))\n"
        f"          (fill (type background)))\n"
        + "\n".join(pins) + "\n"
        f"      )\n"
        f"    )"
    )


# ---------------------------------------------------------------------------
# Mounting-hole symbol (pinless mechanical part)
# ---------------------------------------------------------------------------
def mounting_hole_sym_def():
    return (
        '    (symbol "Mechanical:MountingHole"\n'
        "      (pin_names (offset 1.016))\n"
        "      (exclude_from_sim yes) (in_bom no) (on_board yes)\n"
        '      (property "Reference" "H" (at 0 5.08 0)\n'
        "        (effects (font (size 1.27 1.27))))\n"
        '      (property "Value" "MountingHole" (at 0 3.05 0)\n'
        "        (effects (font (size 1.27 1.27))))\n"
        '      (property "Footprint" "" (at 0 0 0)\n'
        "        (effects (font (size 1.27 1.27)) (hide yes)))\n"
        '      (property "Datasheet" "~" (at 0 0 0)\n'
        "        (effects (font (size 1.27 1.27)) (hide yes)))\n"
        '      (symbol "MountingHole_0_1"\n'
        "        (circle (center 0 0) (radius 1.27)\n"
        "          (stroke (width 0.508) (type default))\n"
        "          (fill (type none)))\n"
        "      )\n"
        "    )"
    )
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

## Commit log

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2026-04-07 BLE reconnect, F12 pairing, software Alpha Lock, debug instrumentation
    Persist the bonded peer address in NVS so the L75 (which advertises
    without the HID UUID after reconnect) is matched by address instead.
    Reconnect now works across both ESP32 reboot and keyboard power cycle.
    Add F12 as the keyboard-side trigger for BLE pairing mode, with the
    BOOT button preserved as the no-working-keyboard escape hatch. The
    shared logic lives in bleEnterPairingMode(); F12 detection is
    edge-triggered in processHidReport and signals bleTask via a flag
    since BLE stack calls aren't safe from the notify callback context.
    Implement Alpha Lock entirely in software by injecting SHIFT into
    letter keypresses when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
    [ti-99-keyboard.ino]
2026-04-21 Add TI Extended BASIC simulator + BleHidHost library + pcb/test sketches
    ti-basic/: ESP32-8048S043 (800x480 RGB panel) port of a TI-99/4A
    Extended BASIC interpreter. Token table, expression parser, exec
    manager, file I/O, V9T9 .dsk image support (read/write DIS/VAR,
    NEWDISK, COPY, CAT/DIR, MOUNT/UNMOUNT DSK1-9/A-Z), DSKUTILS-style
    catalog, paged listing, ON BREAK/ERROR/WARNING + CALL ERR, full
    DEF/SUB support including pass-by-value-result. Tokens match TI
    binary format so PROGRAM files round-trip (Phase 3 pending).
    ti-basic-otg/: frozen earlier port for the ESP32-S3-USB-OTG dev
    board (240x240 SPI display, 4 buttons).
    BleHidHost/: extracted BLE HID host library used by ti-basic and
    ti-99-k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
    [partitions.csv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]
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2026-04-25 PCB rev: replace TXS0108E with BSS138 BOB-12009 modules
    TXS0108E auto-direction detection fails on the open-drain matrix
    emulation the firmware uses, with documented latch-up that damaged
    GPIO 16 on a dev board. BSS138 + 10k pullups is the correct topology
    for a scanned matrix; bench-validated 2026-04-20 across clean
    push-pull, open-drain, and static hold modes.
    Schematic generator (generate_kicad.py) now produces 4x BOB-12009
    sockets (2x 1x6 each, 10mm row spacing) replacing the 2x TXS0108E
    modules. Channel allocation is contiguous per BOB on both ESP32 and
    TI sides to avoid trace crossings. LV and HV nets are intentionally
    distinct ('<sig>_LV' vs '<sig>') since they're isolated through th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
    [ti99-kb-adapter.kicad_pcb, ti99-kb-adapter.kicad_sch]
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2026-04-26 Sprites Phase 1+2; FOR/NEXT correctness; CALL SPEED/DELAY/TIMER
    Sprites:
    - New sprites.h: 28-slot sprite table, magnify modes (1..4), pixel-on
    helper that walks 4 char patterns for 16x16 sprites.
    - Pixel-accurate renderer: each TI pixel becomes 2x2 physical, only ON
    bits drawn so the char grid shows through transparent pixels. Erase
    = re-drawCell on overlapped cells (state lives in screenBuf).
    - CALL SPRITE / DELSPRITE / LOCATE / PATTERN / MAGNIFY (Phase 1) take
    multi-arg forms (e.g. CALL SPRITE(#1,..., #2,..., #3,...)).
    - CALL MOTION + 60 Hz spriteTick() integrator (Phase 2). Velocity is
    vel/8 TI-pixels per frame; sub-pixel accumulators give smooth slow
    motion. Wraps at TI's 192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
2026-04-26 Sprite Phase 3 (POSITION/COINC/DISTANCE) + SAVE/OLD device prefixes + ESP-XB manual
    Sprites Phase 3:
    - CALL POSITION(#n, row-var, col-var [, ...]) — read sprite TI-pixel
    position into BASIC vars, multi-sprite syntax supported.
    - CALL DISTANCE(#a, #b, var) and CALL DISTANCE(#s, row, col, var) —
    returns dr² + dc² (TI's native squared distance, no sqrt).
    - CALL COINC three forms:
    sprite-pair (#a, #b, tolerance, var)
    sprite-point (#s, row, col, tolerance, var)
    ALL form (CALL COINC(ALL, var)) — checks any-pair overlap by
    bounding box.
    - COINC ALL uses sprites::footprint() (body × scale) so mixed-magnify
    collision detection works correctly: 8/16/16/32 px per MAGNIFY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
2026-04-26 File I/O open modes: FIXED + RELATIVE + INTERNAL parse-and-go
    Adds full FIXED-record support and RELATIVE (REC=K) random access on
    FLASH, SDCARD, and DSK images. INTERNAL is recognized but stored as
    DISPLAY (no radix-100 encoding) — flagged as a known limitation in
    KEYWORDS.md and EXTENSIONS.md.
    Two compounding bugs fixed along the way that kept REC=K from working
    at all:
    * "REC" was missing from the lexer's keyword table, so it never
    tokenized to TOK_REC and the seek branch in execPrint/execInput
    never fired.
    * processLine's default dispatcher case advanced one byte past
    TOK_QUOTED_STR / TOK_UNQUOTED_STR / TOK_STRING_LIT, landing on
    the length byte and re-dispatching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
2026-04-26 Add RESTORE #n; refresh KEYWORDS.md test column
    RESTORE #n rewinds an open file to its first record without closing
    it — DSK reader resets curLogicalSector/posInSector/recordsRead/eof,
    FLASH/SD handles byte-seek to 0. Test 43 verifies a two-pass re-read.
    KEYWORDS.md: flip CLOSE, EOF(n), INPUT #, RESTORE #, all 9 sprite
    CALLs, and CALL SPEED/DELAY/TIMER to ✅ Test based on this session's
    verified runs. Drop the duplicate I/O-section DELETE row (already
    covered in immediate-mode commands). V9T9 row now mentions DIS/FIX.
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2026-04-27 Sprite collision demo: 3-way chaos with Pac-Man, Ghost, Invader
    Test 40 Part E now bounces three sprites instead of two — pairwise
    COINC checks across (1,2) (1,3) (2,3), each pair flipping both
    colliders' velocities on hit. Custom 8x8 glyphs at chars 128-130 plus
    a black screen for arcade-cabinet feel.
2026-04-28 Double-buffered RGB panel + sprite render fixes + IF/ELSE bug
    Tear-free graphics via a forked RGB panel (rgb_db.h/.cpp) that flips
    the ESP_LCD num_fbs=2 / double_fb=true flags. CPU writes land in the
    back buffer; tft->flush() commits via esp_lcd_panel_draw_bitmap and
    the panel swaps front/back at vsync. Minimal display class wraps just
    the GFX primitives ti-basic.ino actually uses (writePixel / fillRect /
    draw16bitRGBBitmap / fillScreen / setRotation), so no need to also
    fork Arduino_RGB_Display. setup() and showBootScreen() now call
    flush() at points where the user needs to see the screen before a
    blocking wait.
    Sprite render improvements:
    - Priority correctness: sprite #1 paints last so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
2026-04-28 Sprite snapshots, TI-faithful wrap, layout tweaks, build.bat killmonitor
    Sprite system:
    - POSITION / COINC / DISTANCE now read snapRow/snapCol/snapMagnify
    captured at the end of each spriteTick (the virtual vsync), so a
    BASIC iteration sees a coherent frame even if a tick fires
    mid-iteration. CALL SPRITE / CALL LOCATE seed the snapshot so a
    POSITION right after them returns the just-set value.
    - Toroidal wrap restored at 256 (TI VDP 8-bit register, matches
    pico9918) instead of the visible-screen 192. BASIC programs
    that bounce sprites at the visible edge are responsible for
    their own bounds — same contract as real TI.
    Display:
    - Disabled the gray status b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
2026-04-29 BLE keyboard auto-rescan + gamepad scaffolding
    ble_keyboard.h:
    - Auto-rescan watchdog: when disconnected for >5 s and not in
    pairing mode, request pairing/scan window. Lets keyboards that
    drop into deep sleep reconnect without a reboot.
    - Mirror keyboard arrow keys into joyArrow* globals so CALL JOYST
    works from any BLE keyboard (and from the 8BitDo Zero 2 in
    Keyboard / Switch BLE modes).
    ble_gamepad.h (new):
    - Globals (joyX/joyY/joyFire) read by CALL JOYST.
    - bleGpOnReport() parses non-keyboard HID reports as gamepad
    input (analog stick + hat fallback).
    - bleGpUpdateFromArrows() recomposes joyX/joyY from arrow state.
    BleHidHost.h:
    - Name-substring fallback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
2026-04-30 Move ti-basic-otg to its own repo; gitignore KiCad auto-files
    - Removes ti-basic-otg/ subproject from this repo (continues life as a
    standalone repository).
    - Removes IMG_4174.jpeg (no longer needed).
    - Untracks pcb/.history and pcb/ti99-kb-adapter-backups (auto-generated
    by editor and KiCad on every save) and adds them to .gitignore so
    they no longer clutter git status.
    - Drops stale ti-basic/* gitignore entries; ti-basic was already moved
    to its own repo in a previous commit.
    - Commits latest pcb/ti99-kb-adapter.kicad_pcb layout edits.
    [partitions.csv, ti99-kb-adapter.kicad_pcb]
2026-05-07 Add CLAUDE.md with project context
    Distills hardware (BSS138 over TXS0108E and why), L75 BLE quirks,
    reconnect strategy, software Alpha Lock fix, prior-art framing, and
    PCB notes so future sessions on any machine pick up the context.
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2026-05-08 BLE host: NimBLE port; type-ahead buffer; matrix debounce + observe mode
    - BleHidHost.h: full Bluedroid -> NimBLE port (synced from Scott Adams
    repo). Sees more keyboards (OMOTON KB066, etc.), ~50% less flash,
    ~100KB less RAM. deleteAllBonds() is now usable for unpair.
    - ti-99-keyboard.ino bleTask(): 5s disconnect-watchdog auto-rescan ports
    the L75 wake-from-sleep fix from the Extended BASIC repo. Triggers
    pairing-mode scan so the name-fallback path catches haveUUID=0
    re-advertisements.
    - ti-99-keyboard.ino INPUT_USB temporarily disabled while EspUsbHost API
    drift (onKey vs onKeyboardKey/onReceive) is rewritten upstream.
    - ti-99-keyboard.ino type-ahead buffer: PC-style 16-deep ri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
    [ti-99-keyboard.ino]
2026-05-12 PCB rev 3: BOB pinout fix, ti99-parts library, parallel TI connector
    - Correct BOB-12009 silkscreen pinout (GND at pad 3, rail at pad 4;
    channels 1-4 at pads 6, 5, 2, 1) and reverse TI-to-BOB channel
    mapping so wires route straight across the BOB with no crossings
    - New ti99-parts library (generate_parts.py) with multi-unit symbols
    for BOB-12009 and ESP32-S3-N16R8 plus a custom J13 cable-header
    footprint; one footprint per BOB and ESP32 with row spacing baked
    in, no more manual realignment after Update-from-Schematic
    - Switch ESP32 footprint to Hosyond N16R8 / DevKitC-1 form factor
    and re-orient so pad 1 is at top
    - J13 footprint widened to 3.81mm pitch with 2.0mm drill / 3.0mm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
    [ti99-kb-adapter-B_Cu.gbr, ti99-kb-adapter-B_Mask.gbr, ti99-kb-adapter-B_Silkscreen.gbr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]
2026-07-07 Matrix output: timer-sampled debounced column scanner (typing + QUIT + CLEAR)
    Replace the reactive column-edge ISR with a 200kHz hardware timer that
    samples all six columns with asymmetric debounce (assert on the first low
    sample, release after two consecutive highs) and drives the OR of every
    active column's rows via direct GPIO register writes.
    The release hysteresis fixes coupling-induced duplicate characters (brief
    positive blips on the held column no longer read as key-up/key-down), and
    the OR-of-active-columns presents the deliberately-overlapping two-column
    strobes that the TI's QUIT (FCTN+=) and CLEAR/BREAK (FCTN+4) ROM routines
    use, which a single reactive column driver could never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
    [ti-99-keyboard.ino]
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2026-07-10 README: bring up to date with BSS138 / NimBLE / working matrix
    Correct the long-stale README against the actual hardware and firmware:
    - Level shifters: TXS0108E -> BSS138 discrete (BOB-12009); add why-not-TXS note
    - BLE stack: Bluedroid -> NimBLE-Arduino (and its install step)
    - Board: DevKitC-1 -> Hosyond ESP32-S3 N16R8
    - Cable: dupont -> 15-pin female-to-female ribbon (+ red-stripe gotcha)
    - Fix the scrambled GPIO/pinout table to the real column-input / row-output
    assignment; drop the bogus Alpha-Lock-on-GPIO14 row
    - Describe the timer-sampled debounced matrix scanner
    - Full punctuation/symbol mapping; correct '/' (base key, Shift+/ = ?)
    - Note working QUIT (Alt+=) and CLEAR/BREAK (Alt+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
2026-07-13 BLE: persistent reconnect scan for reliable sleep/wake reconnect
    After the keyboard deep-sleeps (HCI 0x08 supervision timeout) the running firmware only scanned during pairing windows, so reconnect was slow or missed, and the host wasted windows chasing false-HID advertisers (a stray 'Q35...' name matched the HID name filter). BleHidHost now keeps a persistent background scan running whenever a saved peer is disconnected, re-binding it by address the instant it re-advertises. The sketch's 5s pairing-mode watchdog is removed; new keyboards still pair via F12. Bumps BleHidHost to 0.2.0. NOTE: BleHidHost.h is shared verbatim with the Scott Adams and Extended BASIC repos and must be synced.
    Co-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
    [ti-99-keyboard.ino]
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2026-07-18 docs: correct PCB rev history (R1-R3) and document rev-4 fixes
    CLAUDE.md PCB history was stale. Rev 2 (BSS138) is superseded (level-shifter power/GND swapped); rev 3 is the current in-hand board (power/GND fixed, parallel J20 connector, matrix works). Records two rev-4 items: the keyboard ribbon needing a 180-degree twist (J10 net-mapped straight but physically pin-reversed; alpha-lock at pin 6 is the tell) with the reversed-cable workaround, and the now-fixed J13 hole size. README: ribbon BOM row plus a cheap DIY sourcing recipe (Dupont 1x15 housings + no-shell pre-crimped leads).
2026-07-18 v4: rework keyboard connector for a straight-through ribbon
    Rev 1-3 needed the 1x15 ribbon twisted 180 degrees because the connector orientation reverses pin order (J10 pin p <-> TI motherboard pin 16-p). v4 targets a plain straight ribbon instead.
    Firmware (ti-99-keyboard.ino): the 14 matrix lines are remapped -- each signal now drives/reads the GPIO whose J10 pin mirrors to the correct TI pin (pure relabel of the PIN_ROW_*/PIN_COL_* values; matrix tables unchanged). Compiles clean at 32% flash.
    PCB (generate_kicad.py): the one line firmware can't move is the passive ALPHA_LOCK net; its mirror pin (10) holds INT9 = row 6. So a kb_pin() helper swaps ONLY those two nets in copper -- ALPHA_L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
    [generate_kicad.py, ti-99-keyboard.ino]
2026-07-18 v4: full channel fabric per Jon's map -- every J10 pin gets a GPIO
    Implements the connection map for the straight-ribbon rework: all 15
    J10 pins (including alpha lock) now have a level-shifter channel and a
    GPIO, so any future re-pinning is firmware-only, never a new layout.
    BOB#1: GPIO4-7 -> CH4..CH1 -> J10 1-4 (unchanged)
    BOB#2: GPIO15-18 -> CH4..CH1 -> J10 5-8
    BOB#3: GPIO8-11 -> CH4..CH1 -> J10 9-12 (GPIO8 newly in service;
    GPIO9 = alpha lock, J10 10)
    BOB#4: GPIO12-14 -> CH4..CH2 -> J10 13-15 (CH1 spare)
    J10 pin 6 carries INT9 and pin 10 carries ALPHA_LOCK; through the flat
    ribbon (J10 p -> TI 16-p) they land on TI pins 10 and 6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
    [ti99-kb-adapter.kicad_sch]
2026-07-19 pcb: bake 0.5mm default trace width into the generated project file
    make_project() emitted an empty net-class list, so regenerating the .kicad_pro wiped the KiCad-saved design rules (default trace width, toolbar size presets). Bake in the board's standard sizes -- Default net class with 0.5mm track width / 0.2mm clearance / 0.8x0.4mm vias, plus the pre-defined track-width and via lists -- so regens preserve them. Deliberately NOT regenerating here: Jon has the project open mid-layout; his next KiCad save owns the file.
    [generate_kicad.py]
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2026-07-19 v4: routed board layout -- full fabric, J15 spare pad, DRC clean
    Complete v4 re-route against the final netlist: all 16 channels routed (IO3 on alpha lock, IO14 -> BOB#4-CH1 -> J15 SPARE pad placed near the keyboard connectors), 173 tracks all 0.5mm, GND pours on F.Cu/B.Cu with stitching vias, 4x 3mm mounting holes restored (marked board-only so schematic updates can't delete them again), J13 cable-solder pads at 1.1mm drill. DRC: 0 errors, 0 warnings (silk min-text-height relaxed to 0.6mm to match the proven 0.6/0.7mm labels). Project file carries the KiCad-native settings with 0.5mm defaults.
    Verified by script: trace widths, pad sizes, mounting holes, SPARE/alpha connectivity, zones. Rea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
    [ti99-kb-adapter.kicad_pcb]
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2026-07-19 docs: rev-4 J20 takes the original keyboard rotated 180 from OEM orientation
    Bench fact from Jon: the original keyboard mated straight onto rev-3's J20 (and the TI mb header). v4 moved the mirror compensation from the twisted cable into the nets, so on rev-4 the keyboard's plug flips 180. Deterministic install instruction now, not trial-and-error.
2026-07-19 v4: wire J20 as a TI-mb-header clone -- original keyboard plugs in straight
    Jon expects the original keyboard to plug into J20 exactly as it did on rev-3 and on the TI itself. Since v4's J10 nets are pre-mirrored for the flat ribbon, J20 now takes J10 pin (16-j)'s net on its pin j -- a 15-line bus reversal in copper -- making J20 functionally identical to the TI motherboard header (keyboard contact j reaches TI line j, alpha lock contact on the real alpha net).
    Verified: J10 unchanged, all 15 J20 positions carry the reversed nets, alpha/INT9 land on keyboard pins 6/10, net counts intact (HVx3/LVx2, SPARE x2). Net names on J20 read reversed since v4 names are J10-local -- documented. Firmwar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
    [ti99-kb-adapter.kicad_sch]
2026-07-19 Revert "v4: wire J20 as a TI-mb-header clone -- original keyboard plugs in straight"
    This reverts commit 3e78aeb654af4029154dd3c8cdee2553d85470c3.
    [ti99-kb-adapter.kicad_sch]
2026-07-20 loopback rig: order v4 pairs by J10 adjacency for shunt-jumper through-path testing
    Jon runs the loopback test on assembled boards, jumpered at the far end, so the signal traverses the full chain: module solder joints, sockets, carrier traces, and both BSS138 FETs of each BOB channel -- catching every failure mode seen so far (dead GPIO inputs, under-heated BOB joints). Re-pair the v4 test so each pair lands on adjacent J10 pins: the assembled-board fixture becomes seven 2.54mm shunts straight down J10 pins 1-14 plus one wire from J10 pin 15 to the J15 SPARE pad (which also exercises the repair channel through its real pad). Bare-module fixture unchanged in spirit; pairs each GPIO exactly on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
    [test-matrix-loopback.ino]
2026-07-20 v5: mirror J14 daisy-chain output; mounting holes become schematic-owned
    J14 mated the TI motherboard's keyed power plug backwards on every rev to date -- passthrough-mirror principle: the original PSU-MB joint's halves face each other, a passthrough board mounts both interfaces facing the same way, so exactly one must be mirror-wired. J13 is hand-soldered (self-correcting); J14 now carries the mirror (1=+5V, 2=GND, 3=+12V, 4=-5V). Verified in the regenerated schematic (8/8 pin checks; keyboard nets unaffected, 60/60).
    Mounting holes H1-H4 (MountingHole_2.2mm_M2) are now generated into the schematic as pinless mechanical symbols, so F8's delete-orphans can never drop them again. Migration f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
    [ti99-kb-adapter.kicad_sch]
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2026-07-30 docs: capture MX-keyboard fusion concept; power is TI +5V direct (no buck)
    MX_KEYBOARD_CONCEPT.md: future project parked until V5 validates -- one keyboard-size PCB combining local MX switches (7x8 diode matrix via shift registers / I2C expander), the proven 16-channel fabric with on-board BSS138s, and the existing BLE/USB firmware pipeline; local keys are just a third input source. No backlight by decision. Market context: shift838 838-MX99 (, matrix-synthesis micro, no BLE/USB).
    Power correction throughout: the adapter runs on regulated +5V straight from the TI PSU via the J13/J14 daisy-chain -- the originally planned 12V->5V buck converter was never needed. CLAUDE.md header + hardware bu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
2026-07-30 docs: rename the spin's identity v4 -> v5 everywhere; B-P board named
    The branch was created when the fab target was rev 4, but the design became V5 before any board was made -- branch renamed v4 -> v5 and every design-generation reference in docs, firmware comments, generator comments, and the loopback rig updated to match (git tag v3 and historical commit messages untouched). Also fixes a stale comment claiming alpha lock is GPIO9 (it is GPIO3 since the IO3 shift).
    MX_KEYBOARD_CONCEPT.md: working name B-P (BLE + Physical); an 838-MX99 is on order as mechanical reference and for J20-coexistence validation.
    Both sketches compile clean after the comment sweep.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
    [generate_kicad.py, test-matrix-loopback.ino, ti-99-keyboard.ino]
2026-08-07 loopback rig: LED verdict -- green all-pass, red any-fail, blue running
    Batch testing without a serial monitor: the onboard WS2812 (GPIO48, same LED the main sketch uses) shows the verdict at a glance. Requested by Jon for go/no-go board screening.
    [test-matrix-loopback.ino]
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2026-08-07 v7: discrete BSS138 channel cells replace the BOB modules; JLC assembly tooling
    Schematic generator: 16 channel cells (Q1-Q16 BSS138 SOT-23 LCSC C78284; R1-R32 10k 0805 LCSC C17414, JLC Basic) replace the four BOB-12009 daughterboards. Per cell: source on the LV net, drain on the HV net, gate on 3V3, 10k pull-up each side -- topology, nets, and GPIOs identical to V5/V6, zero firmware change. Pull-ups join the FET by drawn wires so each net carries one label; LCSC part numbers ride as hidden symbol properties for the assembly BOM.
    Cell placement uses half-grid rows with column stagger after the verification harness caught two real net-merge bugs (collinear wire overlaps with J10 stubs, then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
    [ti99-kb-adapter.kicad_sch]
2026-08-08 v7: layout checkpoint -- 48 SMT parts placed and routed (pre pin-fix)
    Checkpoint of Jon's discrete-cell layout before the symbol Y-inversion fix lands: the generator attached gate/drain wires at vertically mirrored pin positions (KiCad symbol +Y is up, sheet +Y is down), so every FET's gate and drain nets are swapped in this netlist and the routing that follows it. Banked so the placement work survives the corrective F8 + re-route.
    [ti99-kb-adapter.kicad_pcb]
2026-08-08 v7: fix symbol-vs-sheet Y inversion -- gate/drain nets were swapped on every FET
    KiCad symbol coordinates have +Y up; schematic sheets have +Y down. add_simple returned pin connection points without inverting, so wires attached at vertically mirrored positions: every Q's gate pad got the HV signal net and its drain pad got +3V3. Invisible to net-count checks; caught by the board-level pad-net check after F8 (Q1: gate=/INT5, drain=+3V3). add_simple now inverts y (documented), r_hv follows the drain to its true sheet position, schematic regenerated, all 15 netlist checks pass plus spot-checked wire coordinates.
    The board still carries the swapped netlist from the pre-fix F8: re-run F8, swap t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
    [ti99-kb-adapter.kicad_sch]
2026-08-08 v7: corrected discrete-cell layout -- all 16 FET cells verified, DRC 0/0
    Jon's re-route after the Y-inversion fix: 3V3 distribution and output lines on their correct pads at every FET. Verified pad-by-pad across all 16 cells (G=+3V3, S=<sig>_LV, D=<sig>, both pull-ups matching) plus J14 mirror, J13, H1-H4, J15/SPARE, zones; DRC 0 violations / 0 unconnected. Discrete footprints reported to lay out cleaner than the BOB modules.
    [ti99-kb-adapter.kicad_pcb]
2026-08-08 pcb: V7 order package -- r7 gerbers + JLC assembly BOM/CPL
    Fresh kicad-cli export of the verified discrete-cell board: 7 layers + merged excellon drill (0.3/1.0/1.1/1.8/2.2), zipped as ti99-kb-adapter_r7.zip. JLC assembly files from export_jlc.py: BOM (2 line items -- 16x BSS138 C78284, 32x 10k C17414) and CPL (48 placements, all top-side). Loose layer files now V7; r5 zip retained as the fabbed-V5 archive, r6 as ordered.
    [ti99-kb-adapter-B_Cu.gbl, ti99-kb-adapter-B_Mask.gbs, ti99-kb-adapter-B_Silkscreen.gbo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]
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2026-08-08 pcb: deterministic UUIDs -- regeneration is now byte-identical (idempotent)
    uid() was uuid4, so every generate_kicad.py run rewrote all ~650 UUIDs and left the schematic 'modified' with pure churn (and broke KiCad's UUID-based links across regens). Now uuid5 over a fixed namespace + call counter: the Nth call always yields the same UUID, verified by hashing two consecutive regens (byte-identical). Netlist re-verified, ALL PASS. Committed schematic is the new stable-UUID baseline.
    [ti99-kb-adapter.kicad_sch]
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

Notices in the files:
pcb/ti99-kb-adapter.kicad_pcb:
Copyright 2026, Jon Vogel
